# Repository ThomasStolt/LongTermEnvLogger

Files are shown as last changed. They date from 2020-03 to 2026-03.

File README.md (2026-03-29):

# Long Term Environment Logger

The aim of this project is to measure, store, display and evaluate the temperature in the rooms of a large building over an extended time period. This project has 2 main components:

A. The hardware of the sensor.

B. The server infrastructure to receive, store and display the measurements.

## The Hardware

1. An ultra-low power timer circuit that uses nano-Amps only when asleep and wakes up the entire circuit every approx. 5 minutes for measurement.

2. An LDO voltage regulator that regulates the incoming battery voltage from a LiIon battery to 3.3V

3. A battery voltage sensor that sends the battery voltage to the ESP8266 ADC pin with a voltage divider so that the battery voltage can be monitored.

4. The ESP8266 with a DS18B20 temperature sensor.

5. A small solar cell with a charging circuit, to keep the battery charged for as long as possible.

... and some additional mechanical and electronic components.

The ESP8266 was chosen as the microcontroller. It is versatile, very affordable, has more than enough functionality and information is easy to find.

If you think about it in detail, this project is not quite as trivial as it first appears. Some of the things to consider are:

* Runtime - How long does a single battery last?

  * As the battery-operated temperature sensors are to be distributed throughout a very large building, you want the individual sensors to run for as long as possible, so that you don't have to run around the building changing or charging batteries all the time. One option is the energy-saving mode ("DeepSleep") of the microcontroller. This would reduce the current draw during deep sleep to about 14µA. However, we want to achieve sleep current of less than 100nA! So, the normal Deep-Sleep will not do it.

* Update OTA(?)
	* It might be worth considering adding this capability. This would probably affect the runtime as well, because if we check for updates every time the circuit wakes up, it will cost runtime and energy. So, the question here is, how much runtime this would cost and is this really necessary?

* WiFi Connection Time
	* When the ESP8266 wakes up and has WiFi switched on, it draws about 70mA, which is a lot. So, all efforts need to be taken to reduce the connection time to be a short as possible.

* Power supply / battery
	* Li-Ion batteries are a good energy source for this type of project, especially the 18650 type. They are relatively inexpensive for their capacity. However, as these batteries are very sensitive to mishandling, it is important to take appropriate precautions.
		* How can you ensure that the LiIon battery will not be deep discharged?
		* How can I ensure that the LiIon battery cannot be overcharged?
		* How can I monitor the voltage of the power supply (of the LiIo battery) in order to replace or charge the battery in good time?
		* All batteries must be checked regularly for their capacity and possible health issues.

## Overview

First a short diagram for an overview:

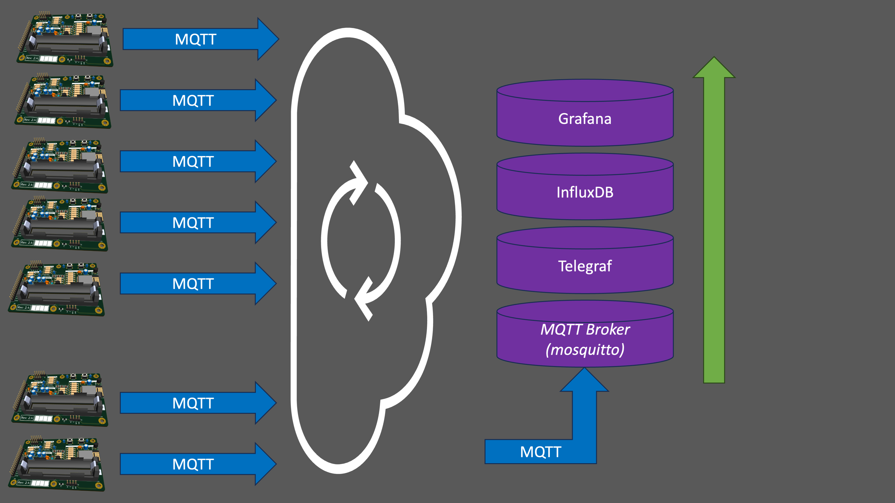
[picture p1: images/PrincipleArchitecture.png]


---

## Programmer Tool

An interactive TUI (terminal user interface) that programs each sensor in two steps. Built with [Textual](https://textual.textualize.io/) for a comfortable dark-mode interface.

### Features

- Auto-detects USB serial ports (OTA/network ports filtered out) and pre-selects the right one
- Live hotplug detection — plug in the adapter and it appears immediately
- Parallel background compilation while you prepare the hardware
- Auto-selects the WiFi network from your credentials file (strongest signal)
- Two-column credentials panel — file list on the left, network config on the right; press `E` to edit
- Per-location sensor registry (`sensors_home.csv`, `sensors_school.csv`, …) — switches automatically with the selected credentials file
- Always-visible Serial Debug panel showing raw ESP output during setup-sketch read
- Adjustable baud rate selector and automatic retry loop on serial read timeout
- Full keyboard navigation — no mouse required
- Clean two-step workflow with progress feedback

### Prerequisites

- [arduino-cli](https://arduino.github.io/arduino-cli/) with the ESP8266 core installed:
  ```bash
  arduino-cli core install esp8266:esp8266
  ```
- Python 3.10+
  ```bash
  pip install -r tool/requirements.txt
  ```

### Credentials Setup

```bash
cp credentials.example.h credentials_Home.h
# Edit credentials_Home.h and fill in your SSID and password
```

You can have multiple credential files for different locations:
- `credentials_Home.h`
- `credentials_School.h`

These files are gitignored — never commit real credentials.

### Board Configuration

Edit `tool/arduino_config.py` if needed:
```python
BOARD_FQBN = "esp8266:esp8266:generic"  # change for your ESP8266 variant
```

Common FQBNs:
- `esp8266:esp8266:generic` — bare ESP-01/ESP-12 modules
- `esp8266:esp8266:nodemcuv2` — NodeMCU v2 / Lolin
- `esp8266:esp8266:d1_mini` — Wemos D1 Mini

### Running the Tool

Connect the ESP8266 via USB-TTL adapter, then:

```bash
cd tool && python3 ltl_programmer.py
```

**Keyboard shortcuts:**

| Key | Action |
|-----|---|
| `F` | Start flash workflow |
| `R` | Refresh port list |
| `E` | Edit network config for selected credentials |
| `Q` | Quit |
| `Enter` | Confirm / Continue |

**Workflow:**

1. Select your USB-TTL adapter port (pre-selected automatically)
2. Select the credentials location (Home, School, …)
3. Press `F` to start — the tool guides you through:
   - Enter flash mode (RST + FLASH button sequence)
   - Setup sketch uploads and reads MAC address, DS18B20 address, and nearby WiFi
   - WiFi network is auto-selected from your credentials file
   - Enter a room number (1–254)
   - Production firmware compiles and uploads with all values baked in
4. Sensor is recorded in `tool/sensors_<location>.csv` (one file per credentials location)

### Flash Mode (ESP-12 / bare modules)

Bare ESP8266 modules without an auto-reset circuit require manual flash mode entry:

1. Press and hold **RST**
2. Press and hold **FLASH**
3. Release **RST**
4. Release **FLASH**

The tool will prompt you at the right moment.

### Manual Flash Fallback

If arduino-cli is not available, you can flash manually using the Arduino IDE:

1. Flash `code/LTL_setup/LTL_setup.ino` and open Serial Monitor at 115200 baud
2. Note the MAC address and DS18B20 address
3. Edit `code/LTL_sensor/LTL_sensor.ino` — replace the placeholder values
4. Copy your `credentials_<location>.h` to `credentials.h` in the same folder
5. Flash `code/LTL_sensor/LTL_sensor.ino`

### Sensor Registry

`tool/sensors_<location>.csv` tracks all programmed sensors per location (gitignored). For example, `sensors_home.csv` and `sensors_school.csv` are created automatically when you first flash a sensor using that credentials file.

| Field | Description |
|---|---|
| timestamp | When the sensor was programmed |
| room_number | Room number (also last IP octet) |
| mac_address | ESP8266 MAC address |
| ds18b20_address | DS18B20 OneWire address |
| location | Credentials location used |
| ssid | WiFi network name |
| bssid | Pinned BSSID (empty if not pinned) |
| channel | Pinned channel (empty if not pinned) |

### Battery Life Optimization

The production firmware (`code/LTL_sensor/LTL_sensor.ino`) reduces ESP8266 awake time by ~1060–1480ms per 5-minute cycle compared to the original firmware:

| Optimization | Saving |
|---|---|
| 9-bit DS18B20 resolution (±0.5°C) + async overlap | ~750ms |
| Hardcoded DS18B20 address (no bus scan) | ~10–30ms |
| Post-publish delays removed | ~300ms |
| **Total without BSSID pinning** | **~1060–1080ms** |
| Optional BSSID/channel pinning | +~200–400ms |
| **Total with BSSID pinning** | **~1260–1480ms** |

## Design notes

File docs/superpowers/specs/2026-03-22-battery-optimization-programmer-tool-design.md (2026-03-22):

# Design Spec: Battery Optimization & Programmer Tool
**Date:** 2026-03-22
**Project:** LongTermEnvLogger

---

## Overview

This spec covers two related improvements to the LongTermEnvLogger project:

1. **Optimized production firmware** (`LTL_sensor.ino`) — reduces ESP8266 awake time per cycle by ~1050–1480ms through sensor resolution reduction, async measurement overlap, hardcoded sensor address, and optional BSSID/channel pinning.
2. **Interactive programmer tool** (`ltl_programmer.py`) — a Python CLI tool that guides a two-step flash workflow: first a setup sketch to read hardware addresses and scan WiFi, then the final production firmware with all values baked in.

---

## Context

The ESP8266 is woken by external hardware every 5 minutes, measures temperature and battery voltage, publishes both to an MQTT broker, then cuts its own power by setting GPIO15 HIGH. Minimizing awake time directly extends battery life.

The existing code (`LTL_2024_01_07_01.ino`) already uses static IP and WiFi sleep before measurement. The main remaining inefficiencies are:
- DS18B20 operating at 12-bit resolution (750ms conversion, blocking)
- OneWire bus enumeration on every boot (~10–30ms)
- 300ms of post-publish delays of unclear necessity
- No BSSID/channel pinning (channel scan on every WiFi connect, ~200–400ms)

---

## Directory Structure

```
LongTermEnvLogger/
├── code/
│   ├── LTL_sensor/
│   │   └── LTL_sensor.ino          # optimized production firmware
│   └── LTL_setup/
│       └── LTL_setup.ino           # one-time setup sketch for configuration
├── tool/
│   ├── ltl_programmer.py           # interactive programmer tool
│   ├── sensors.csv                 # auto-maintained sensor registry (path relative to script)
│   └── arduino_config.py           # board FQBN and baud rate constants
├── credentials_Home.h              # gitignored, real credentials
├── credentials_School.h            # gitignored, real credentials
├── credentials.example.h           # in repo, template for new setups
└── README.md                       # updated with full workflow documentation
```

---

## Firmware Optimizations (`LTL_sensor.ino`)

### DS18B20 Resolution

Call `sensors.begin()` in `setup()` as before, then immediately call `sensors.setResolution(sensorAddr, 9)` to set 9-bit resolution. This must happen in `setup()`, after `sensors.begin()`, before `loop()` runs. It reduces conversion time from ~750ms to ~94ms.

```cpp
void setup() {
  WiFi.forceSleepBegin();
  sensors.begin();
  sensors.setResolution(sensorAddr, 9);   // set once; persists in sensor EEPROM
  pinMode(DONE, OUTPUT);
}
```

### Async Temperature Conversion

In `loop()`, use `sensors.setWaitForConversion(false)` before `requestTemperatures()`. The conversion runs in the background while WiFi connects (~2s) and the MQTT broker connects. The full blocking conversion time (~750ms at 12-bit) is removed from the critical path.

**Order of operations:**
```
setup():
  1. WiFi.forceSleepBegin()
  2. sensors.begin()
  3. sensors.setResolution(sensorAddr, 9)
  4. pinMode(DONE, OUTPUT)

loop():
  1. ADC voltage read (abort if below volt_limit)
  2. sensors.setWaitForConversion(false)
  3. requestTemperatures()          (returns immediately, starts 94ms conversion)
  4. setup_wifi()                   (~2000ms — conversion completes during this)
  5. reconnect()                    (MQTT connect — additional time buffer)
  6. sensors.getTempC(sensorAddr)   (data already ready; uses address, not index)
  7. publish temp + volt
  8. digitalWrite(DONE, HIGH)
```

**Note:** `getTempC(sensorAddr)` must be used (not `getTempCByIndex(0)`). `getTempCByIndex` triggers a bus re-enumeration and defeats the hardcoded-address optimisation.

**Race condition guard:** If BSSID pinning is enabled and WiFi connects faster than 94ms, the conversion may not be complete when `getTempC()` is called. The `reconnect()` call after `setup_wifi()` adds additional time (its internal `delay(100)` polling loop), but this is not guaranteed to be sufficient if the broker also responds immediately. Therefore: when `USE_BSSID` is defined, place `delay(100)` immediately before `getTempC(sensorAddr)` — after both `setup_wifi()` and `reconnect()` have returned — to guarantee 94ms has elapsed since `requestTemperatures()`. Without BSSID pinning the ~2s WiFi connect time makes this guard unnecessary.

### Hardcoded DS18B20 Address

The sensor address (8 bytes) is stored as a constant. This skips OneWire bus enumeration on every boot (~10–30ms).

```cpp
DeviceAddress sensorAddr = { 0x28, 0xXX, 0xXX, 0xXX, 0xXX, 0xXX, 0xXX, 0xXX };
```

This value is substituted by the programmer tool. See Template Substitution section.

### Optional BSSID/Channel Pinning

A compile-time flag enables BSSID + channel hardcoding, skipping the WiFi channel scan (~200–400ms). Disabled by default.

```cpp
// #define USE_BSSID   // uncomment to enable BSSID/channel pinning
#ifdef USE_BSSID
  const uint8_t wifi_bssid[6] = { 0xXX, 0xXX, 0xXX, 0xXX, 0xXX, 0xXX };
  const int wifi_channel = X;
#endif
```

The `WiFi.begin()` call must also be conditional:

```cpp
#ifdef USE_BSSID
  WiFi.begin(ssid, password, wifi_channel, wifi_bssid);
#else
  WiFi.begin(ssid, password);
#endif
```

When `USE_BSSID` is active, add `delay(100)` immediately before `getTempC(sensorAddr)` in `loop()` (see race condition guard above).

Note: The existing firmware has an unconditional `wifi_bssid` array (unused). The new code replaces this with the `#ifdef USE_BSSID` guard.

### Post-Publish Delays

The `delay(100)` and `delay(200)` after MQTT publishes are commented out. Their original purpose is unknown. A comment marks them for easy re-enabling if publish reliability issues arise.

```cpp
client.publish(temp_topic, tempString);
// delay(100);  // original delay, purpose unknown — re-enable if publish reliability issues occur
client.publish(volt_topic, payload);
// delay(200);  // original delay, purpose unknown — re-enable if publish reliability issues occur
```

### Timing Summary

| Optimisation | Critical-path saving |
|---|---|
| 9-bit + async overlap (removes full 750ms blocking call) | ~750ms |
| Hardcoded DS18B20 address (no bus enumeration) | ~10–30ms |
| Post-publish delays removed | ~300ms |
| **Total (without BSSID pinning)** | **~1060–1080ms** |
| Optional: BSSID/channel pinning | +~200–400ms |
| **Total (with BSSID pinning)** | **~1260–1480ms** |

---

## Setup Sketch (`LTL_setup.ino`)

Flashed once before the production firmware. On boot it outputs structured data over Serial at **115200 baud**.

### Output Format

Each line is prefixed with a token. The tool parses by prefix.

**MAC address** (one line):
```
MAC:AA:BB:CC:DD:EE:FF
```

**DS18B20 address** (one line, 8 bytes as uppercase hex, comma-separated, C-array style):
```
DS18B20:0x28,0xFF,0xA1,0xB2,0xC3,0xD4,0xE5,0x06
```

**WiFi networks** (one line per network, pipe-delimited fields: SSID|BSSID|channel|RSSI):
```
WIFI:MyNetwork|AA:BB:CC:DD:EE:FF|6|-72
WIFI:OtherNet|11:22:33:44:55:66|11|-85
```

**End marker** (signals all data has been sent):
```
SETUP_DONE
```

### Error Outputs

If no DS18B20 is found on the bus:
```
DS18B20:NOT_FOUND
```

If WiFi scan returns zero results:
```
WIFI:NONE
```

---

## Programmer Tool (`ltl_programmer.py`)

**Requirements:** Python 3.8+, `rich`, `pyserial`, `arduino-cli` in PATH.

### Board Configuration (`arduino_config.py`)

```python
BOARD_FQBN = "esp8266:esp8266:generic"   # adjust for your ESP8266 variant
BAUD_RATE = 115200
SERIAL_TIMEOUT_S = 30  # seconds to wait for SETUP_DONE before aborting
```

The FQBN can also be auto-detected via `arduino-cli board list` after connecting the device; the tool attempts auto-detection first and falls back to the configured constant.

### Tool Workflow

```
Step 1 — Hardware selection
  ├── Run `arduino-cli board list` to detect connected boards
  ├── Also enumerate serial ports via pyserial
  ├── Merge both lists into a single numbered list, deduplicated by port name
  │    (arduino-cli entry takes precedence when a port appears in both lists)
  └── User selects port (numbered list)

Step 2 — Location / credentials selection
  ├── Scan for credentials_*.h files in project root (relative to script location)
  └── User selects location (e.g. Home, School)

Step 3 — Flash setup sketch
  └── arduino-cli compile --fqbn <FQBN> + upload --port <PORT> LTL_setup.ino
      Error: if arduino-cli not found → print install instructions and abort

Step 4 — Read setup data (serial, timeout = SERIAL_TIMEOUT_S)
  ├── Read lines until SETUP_DONE or timeout
  ├── On timeout → print error, suggest checking baud rate and boot mode, abort
  ├── Parse MAC:     → store and display
  ├── Parse DS18B20: → if NOT_FOUND → print error "No DS18B20 detected", abort
  ├── Parse WIFI:    → collect all networks
  └── If WIFI:NONE   → print warning "No WiFi networks found", BSSID selection skipped

Step 5 — Configuration
  ├── Display WiFi networks as colored rich table (columns: #, SSID, BSSID, Ch, Signal bar)
  ├── Ask: "Select network number for BSSID pinning, or press Enter to skip"
  │    └── If skipped: BSSID/channel columns in CSV are written as empty string ""
  └── Enter room number (validated: integer 1–254, checked for uniqueness in sensors.csv)

Step 6 — Build and flash production firmware
  ├── Copy code/LTL_sensor/LTL_sensor.ino to a temp build directory
  ├── Apply template substitutions (see Template Substitution section)
  ├── Copy selected credentials_<location>.h to temp dir as credentials.h
  ├── arduino-cli compile + upload from temp dir
  └── On success: print confirmation panel

Step 7 — Update sensor registry
  └── Append row to tool/sensors.csv (path relative to script location)
```

### Template Substitution

`LTL_sensor.ino` contains placeholder tokens (C-style comments) that the tool replaces with `str.replace()`:

| Placeholder in .ino | Replaced with |
|---|---|
| `/*ROOM_NUMBER*/101` | actual room number |
| `/*DS18B20_ADDR*/{ 0x28, 0x00, 0x00, 0x00, 0x00, 0x00, 0x00, 0x00 }` | sensor address bytes |
| `// #define USE_BSSID` | `#define USE_BSSID` (if BSSID selected) |
| `/*BSSID*/{ 0x00,0x00,0x00,0x00,0x00,0x00 }` | selected BSSID bytes |
| `/*WIFI_CHANNEL*/1` | selected channel number |

The placeholder includes a default value so the template `.ino` compiles standalone in Arduino IDE without substitution.

**When BSSID pinning is skipped:** only the `USE_BSSID` line substitution is omitted (the line stays commented out). The `/*BSSID*/` and `/*WIFI_CHANNEL*/` placeholders are inside the disabled `#ifdef USE_BSSID` block and are compiled out — the tool does not need to substitute them in this case.

### CSV Schema

File: `tool/sensors.csv` (relative to script location).

```
timestamp,room_number,mac_address,ds18b20_address,location,ssid,bssid,channel
2026-03-22T14:30:00,101,AA:BB:CC:DD:EE:FF,0x28:0xFF:...,Home,MyNetwork,EE:55:A8:2C:A8:64,6
```

One row per programming event. Multiple rows for the same room number are allowed (history preserved). The tool warns if a room number already exists in the CSV and asks for confirmation before proceeding.

---

## Credentials Management

### File Format

`credentials_<location>.h`:
```cpp
const char* ssid = "MyNetwork";
const char* password = "MyPassword";
```

### Build-time inclusion

The tool copies the selected `credentials_<location>.h` to the temp build directory as `credentials.h`. The sketch `#include "credentials.h"` therefore always resolves. The original location-named file is never modified.

### Repository

- `credentials_*.h` files are listed in `.gitignore`
- `credentials.example.h` is committed as a template with placeholder values
- `README.md` documents: copy example → rename to `credentials_<location>.h` → fill in real values

---

## README Updates

The README will document:
1. **Prerequisites:** `arduino-cli` (with ESP8266 core installed), Python 3.8+, `pip install rich pyserial`
2. **Credentials setup:** copy `credentials.example.h`, rename to `credentials_<location>.h`, fill in values
3. **Full programmer tool workflow:** step-by-step with expected terminal output
4. **`arduino_config.py`:** how to set the correct FQBN for your ESP8266 variant
5. **Manual flash fallback:** for environments without arduino-cli

---

## Out of Scope

- No OTA update support
- No change to MQTT topic structure
- No change to 5-minute wake interval (controlled by external hardware)
- `volt_limit` constant remains hardcoded in the sketch (not configurable via tool)
- No Windows-specific serial port handling beyond what pyserial provides natively

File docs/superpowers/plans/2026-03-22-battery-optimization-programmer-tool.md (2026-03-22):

# Battery Optimization & Programmer Tool — Implementation Plan

> **For agentic workers:** REQUIRED SUB-SKILL: Use superpowers:subagent-driven-development (recommended) or superpowers:executing-plans to implement this plan task-by-task. Steps use checkbox (`- [ ]`) syntax for tracking.

**Goal:** Reduce ESP8266 awake time by ~1050–1480ms per 5-minute cycle and provide an interactive Python tool that flashes setup + production firmware with all sensor-specific values baked in.

**Architecture:** Two Arduino sketches (setup sketch outputs hardware info over serial; production sketch has hardcoded DS18B20 address, room number, optional BSSID). Python tool orchestrates two-step flash via arduino-cli, reads serial data, substitutes template placeholders, and maintains a CSV sensor registry.

**Tech Stack:** Arduino/ESP8266, C++, Python 3.8+, `rich`, `pyserial`, `pytest`, `arduino-cli`

**Spec:** `docs/superpowers/specs/2026-03-22-battery-optimization-programmer-tool-design.md`

---

## File Map

| File | Action | Responsibility |
|---|---|---|
| `code/LTL_sensor/LTL_sensor.ino` | Create | Optimized production firmware template |
| `code/LTL_setup/LTL_setup.ino` | Create | One-time setup sketch (MAC, DS18B20 addr, WiFi scan) |
| `tool/ltl_programmer.py` | Create | Interactive two-step programmer tool |
| `tool/arduino_config.py` | Create | Board FQBN, baud rate, timeout constants |
| `tool/requirements.txt` | Create | Python dependencies |
| `tool/tests/__init__.py` | Create | Makes tests a package |
| `tool/tests/test_utils.py` | Create | Unit tests for all pure utility functions |
| `credentials.example.h` | Create | Credential template for the repository |
| `.gitignore` | Modify | Add `credentials_*.h` pattern |
| `README.md` | Modify | Add programmer tool workflow section |

---

## Task 1: Project Scaffolding

**Files:**
- Modify: `.gitignore`
- Create: `credentials.example.h`
- Create: `tool/requirements.txt`
- Create: `tool/pytest.ini`
- Create: `tool/tests/__init__.py`

- [ ] **Step 1: Update .gitignore**

Replace current content of `.gitignore`:
```
credentials.h
credentials_*.h
.DS_Store
tool/sensors.csv
```

- [ ] **Step 2: Create credentials.example.h**

Create `credentials.example.h` in project root:
```cpp
// Copy this file to credentials_<location>.h (e.g. credentials_Home.h)
// and fill in your WiFi credentials.
// credentials_*.h files are gitignored — never commit real credentials.
const char* ssid = "YOUR_SSID_HERE";
const char* password = "YOUR_PASSWORD_HERE";
```

- [ ] **Step 3: Create tool/requirements.txt**

```
rich>=13.0.0
pyserial>=3.5
pytest>=7.0.0
```

- [ ] **Step 4: Create tool/pytest.ini**

```ini
[pytest]
testpaths = tests
```

- [ ] **Step 5: Create tool/tests/__init__.py**

Empty file:
```python
```

- [ ] **Step 6: Install dependencies**

```bash
cd tool && pip install -r requirements.txt
```

Expected: packages install without errors.

- [ ] **Step 7: Commit**

```bash
git add .gitignore credentials.example.h tool/requirements.txt tool/pytest.ini tool/tests/__init__.py
git commit -m "feat: add project scaffolding for programmer tool"
```

---

## Task 2: LTL_sensor.ino — Optimized Production Firmware

**Files:**
- Create: `code/LTL_sensor/LTL_sensor.ino`

This is the production firmware template. Placeholders (C-style comment tokens before default values) are substituted by `ltl_programmer.py` at flash time.

- [ ] **Step 1: Create code/LTL_sensor/LTL_sensor.ino**

```cpp
#include <ESP8266WiFi.h>
#include <PubSubClient.h>
#include <OneWire.h>
#include <DallasTemperature.h>
#include "credentials.h"

// Room number — substituted by ltl_programmer.py (must be 1–254, used as IP last octet)
const int roomNumber = /*ROOM_NUMBER*/101;

// DS18B20 sensor address — substituted by ltl_programmer.py
// Flash LTL_setup.ino once to discover this address
DeviceAddress sensorAddr = /*DS18B20_ADDR*/{ 0x28, 0x00, 0x00, 0x00, 0x00, 0x00, 0x00, 0x00 };

// Voltage limit (~2.7V) — prevents LiIon deep discharge
const int volt_limit = 560;

// Static IP (last octet = room number)
IPAddress staticIP(192, 168, 120, roomNumber);
IPAddress gateway(192, 168, 120, 1);
IPAddress subnet(255, 255, 255, 0);
IPAddress dns(192, 168, 120, 1);

// Optional BSSID/channel pinning — saves ~200-400ms per cycle by skipping WiFi channel scan.
// Only reliable with a single fixed access point on a manually configured fixed channel.
// ltl_programmer.py uncomments this line when a BSSID is selected during programming.
// #define USE_BSSID
#ifdef USE_BSSID
  const uint8_t wifi_bssid[6] = /*BSSID*/{ 0x00, 0x00, 0x00, 0x00, 0x00, 0x00 };
  const int wifi_channel = /*WIFI_CHANNEL*/1;
#endif

const char* mqtt_server = "192.168.120.2";
const int mqtt_port = 1883;
char temp_topic[30];
char volt_topic[30];

#define ONE_WIRE_BUS 12
#define DONE 15
OneWire oneWire(ONE_WIRE_BUS);
DallasTemperature sensors(&oneWire);

WiFiClient espClient;
PubSubClient client(espClient);

void setup_wifi() {
  unsigned long startAttemptTime = millis();
  WiFi.forceSleepWake();
  char hostname[11];
  sprintf(hostname, "sensor_%03d", roomNumber);
  WiFi.hostname(hostname);
  WiFi.config(staticIP, gateway, subnet, dns);
#ifdef USE_BSSID
  WiFi.begin(ssid, password, wifi_channel, wifi_bssid);
#else
  WiFi.begin(ssid, password);
#endif
  while (WiFi.status() != WL_CONNECTED && millis() - startAttemptTime < 5000) {
    delay(100);
  }
  if (WiFi.status() != WL_CONNECTED) {
    digitalWrite(DONE, HIGH);
    return;  // hardware cuts power immediately; return ensures no further code runs
  }
}

void reconnect() {
  char clientId[20];
  sprintf(clientId, "room_%03d", roomNumber);
  sprintf(temp_topic, "sensor/temp/%03d", roomNumber);
  sprintf(volt_topic, "sensor/volt/%03d", roomNumber);
  client.setServer(mqtt_server, mqtt_port);
  unsigned long startAttemptTime = millis();  // unsigned long matches millis() return type
  while (!client.connected()) {
    if (client.connect(clientId)) {
      break;
    } else {
      delay(100);
      if (millis() - startAttemptTime > 5000) {
        digitalWrite(DONE, HIGH);
        return;  // hardware cuts power immediately; return ensures no further code runs
      }
    }
  }
}

void setup() {
  WiFi.forceSleepBegin();
  sensors.begin();
  sensors.setResolution(sensorAddr, 9);  // 9-bit: ~94ms conversion, ±0.5°C. Persists in sensor EEPROM.
  pinMode(DONE, OUTPUT);
}

void loop() {
  // Check battery voltage — power off immediately if below deep-discharge limit
  int adcValue = analogRead(A0);
  if (adcValue < volt_limit) {
    digitalWrite(DONE, HIGH);
    return;
  }
  char voltPayload[5];
  snprintf(voltPayload, sizeof(voltPayload), "%d", adcValue);

  // Start async temperature conversion (94ms at 9-bit resolution).
  // WiFi + MQTT connect (~2s total) runs while the DS18B20 converts in the background,
  // so the conversion adds zero time to the critical path.
  sensors.setWaitForConversion(false);
  sensors.requestTemperatures();

  setup_wifi();
  if (!client.connected()) { reconnect(); }
  client.loop();

#ifdef USE_BSSID
  // With BSSID pinning, WiFi may connect in <94ms — add guard to ensure conversion is complete.
  delay(100);
#endif

  // Read temperature — conversion guaranteed complete by now
  float temperature = sensors.getTempC(sensorAddr);
  char tempString[8];
  dtostrf(temperature, 1, 2, tempString);

  client.publish(temp_topic, tempString);
  // delay(100);  // original delay — purpose unknown; re-enable if publish reliability issues occur
  client.publish(volt_topic, voltPayload);
  // delay(200);  // original delay — purpose unknown; re-enable if publish reliability issues occur

  // Cut power to the entire circuit
  digitalWrite(DONE, HIGH);
}
```

- [ ] **Step 2: Verify the template compiles in Arduino IDE (manual check)**

Open `code/LTL_sensor/LTL_sensor.ino` in Arduino IDE with a `credentials.h` present. It should compile without errors. The default DS18B20 placeholder address `{ 0x28, 0x00, ... }` is valid C++ and will compile fine (it just won't work until substituted).

- [ ] **Step 3: Commit**

```bash
git add code/LTL_sensor/LTL_sensor.ino
git commit -m "feat: add optimized LTL_sensor firmware template with async DS18B20 and placeholder tokens"
```

---

## Task 3: LTL_setup.ino — Setup Sketch

**Files:**
- Create: `code/LTL_setup/LTL_setup.ino`

This sketch runs once during programming. It outputs MAC address, DS18B20 address, and WiFi scan results over serial at 115200 baud. It does **not** need `credentials.h` (it scans WiFi without connecting).

- [ ] **Step 1: Create code/LTL_setup/LTL_setup.ino**

```cpp
#include <ESP8266WiFi.h>
#include <OneWire.h>
#include <DallasTemperature.h>

// LTL Setup Sketch
// Flash once to discover DS18B20 address, ESP MAC address, and nearby WiFi networks.
// Output is read by ltl_programmer.py to configure the production firmware.
// Serial: 115200 baud. Output ends with SETUP_DONE.

#define ONE_WIRE_BUS 12
OneWire oneWire(ONE_WIRE_BUS);
DallasTemperature sensors(&oneWire);

void setup() {
  Serial.begin(115200);
  delay(500);  // Let serial port stabilise after boot

  // MAC address
  WiFi.mode(WIFI_STA);
  Serial.print("MAC:");
  Serial.println(WiFi.macAddress());

  // DS18B20 address
  sensors.begin();
  if (sensors.getDeviceCount() == 0) {
    Serial.println("DS18B20:NOT_FOUND");
  } else {
    DeviceAddress addr;
    sensors.getAddress(addr, 0);
    Serial.print("DS18B20:");
    for (int i = 0; i < 8; i++) {
      if (i > 0) Serial.print(",");
      Serial.print("0x");
      if (addr[i] < 0x10) Serial.print("0");  // zero-pad single hex digits
      Serial.print(addr[i], HEX);
    }
    Serial.println();
  }

  // WiFi scan (no connection needed — passive scan only)
  int n = WiFi.scanNetworks();
  if (n == 0) {
    Serial.println("WIFI:NONE");
  } else {
    for (int i = 0; i < n; i++) {
      // Format: WIFI:SSID|BSSID|channel|RSSI
      Serial.print("WIFI:");
      Serial.print(WiFi.SSID(i));
      Serial.print("|");
      Serial.print(WiFi.BSSIDstr(i));
      Serial.print("|");
      Serial.print(WiFi.channel(i));
      Serial.print("|");
      Serial.println(WiFi.RSSI(i));
    }
  }

  Serial.println("SETUP_DONE");
}

void loop() {}  // nothing to do after setup
```

- [ ] **Step 2: Verify the sketch compiles in Arduino IDE (manual check)**

No `credentials.h` needed. Should compile cleanly.

- [ ] **Step 3: Commit**

```bash
git add code/LTL_setup/LTL_setup.ino
git commit -m "feat: add LTL_setup sketch for hardware discovery"
```

---

## Task 4: Tool Foundation — arduino_config.py and ltl_programmer.py Skeleton

**Files:**
- Create: `tool/arduino_config.py`
- Create: `tool/ltl_programmer.py`

- [ ] **Step 1: Create tool/arduino_config.py**

```python
# arduino_config.py — board configuration for ltl_programmer.py
# Adjust BOARD_FQBN to match your ESP8266 variant.
# Common values:
#   esp8266:esp8266:generic          — bare ESP-01/ESP-12 modules
#   esp8266:esp8266:nodemcuv2        — NodeMCU v2 / Lolin
#   esp8266:esp8266:d1_mini          — Wemos D1 Mini
BOARD_FQBN = "esp8266:esp8266:generic"
BAUD_RATE = 115200
SERIAL_TIMEOUT_S = 30  # seconds to wait for SETUP_DONE before aborting
BOOT_DELAY_S = 2       # seconds to wait for ESP8266 to boot after upload
```

- [ ] **Step 2: Create tool/ltl_programmer.py skeleton**

```python
#!/usr/bin/env python3
"""LTL Sensor Programmer — interactive two-step ESP8266 flash tool.

Workflow:
  1. Select serial port
  2. Select WiFi credentials location
  3. Flash LTL_setup sketch → read MAC, DS18B20 address, WiFi networks
  4. Configure room number and optional BSSID pinning
  5. Flash production firmware with values baked in
  6. Record to sensors.csv
"""

import csv
import os
import re
import shutil
import subprocess
import sys
import tempfile
import time
from datetime import datetime
from pathlib import Path

import serial
import serial.tools.list_ports
from rich.console import Console
from rich.panel import Panel
from rich.prompt import Confirm, IntPrompt, Prompt
from rich.table import Table

sys.path.insert(0, str(Path(__file__).parent))
from arduino_config import BAUD_RATE, BOARD_FQBN, BOOT_DELAY_S, SERIAL_TIMEOUT_S

console = Console()

# ── Paths ────────────────────────────────────────────────────────────────────
PROJECT_ROOT = Path(__file__).parent.parent
SETUP_SKETCH_DIR = PROJECT_ROOT / "code" / "LTL_setup"
SENSOR_SKETCH = PROJECT_ROOT / "code" / "LTL_sensor" / "LTL_sensor.ino"
CSV_PATH = Path(__file__).parent / "sensors.csv"
CSV_FIELDNAMES = [
    "timestamp", "room_number", "mac_address", "ds18b20_address",
    "location", "ssid", "bssid", "channel",
]

# ── Pure utility functions (unit-tested in tests/test_utils.py) ──────────────

# ── arduino-cli functions ────────────────────────────────────────────────────

# ── UI functions ─────────────────────────────────────────────────────────────

# ── Main workflow ─────────────────────────────────────────────────────────────

def main():
    console.print(Panel.fit(
        "[bold cyan]LTL Sensor Programmer[/bold cyan]\n"
        "Two-step ESP8266 flash tool",
        border_style="cyan",
    ))
    console.print("[yellow]Not yet implemented — run after completing all tasks.[/yellow]")

if __name__ == "__main__":
    main()
```

- [ ] **Step 3: Verify the skeleton runs**

```bash
cd tool && python ltl_programmer.py
```

Expected: prints the cyan header panel and the "Not yet implemented" message.

- [ ] **Step 4: Commit**

```bash
git add tool/arduino_config.py tool/ltl_programmer.py
git commit -m "feat: add tool foundation — arduino_config.py and ltl_programmer.py skeleton"
```

---

## Task 5: Serial Output Parser (TDD)

**Files:**
- Modify: `tool/ltl_programmer.py` (add `parse_serial_output`)
- Modify: `tool/tests/test_utils.py` (add parser tests)

- [ ] **Step 1: Write failing tests**

Create `tool/tests/test_utils.py`:

```python
import sys
from pathlib import Path
sys.path.insert(0, str(Path(__file__).parent.parent))

from ltl_programmer import parse_serial_output

def test_parse_full_output():
    lines = [
        "MAC:AA:BB:CC:DD:EE:FF",
        "DS18B20:0x28,0xFF,0xA1,0xB2,0xC3,0xD4,0xE5,0x06",
        "WIFI:HomeNet|AA:BB:CC:DD:EE:FF|6|-72",
        "WIFI:OtherNet|11:22:33:44:55:66|11|-85",
        "SETUP_DONE",
    ]
    result = parse_serial_output(lines)
    assert result["mac"] == "AA:BB:CC:DD:EE:FF"
    assert result["ds18b20"] == "0x28,0xFF,0xA1,0xB2,0xC3,0xD4,0xE5,0x06"
    assert result["ds18b20_error"] is False
    assert len(result["wifi_networks"]) == 2
    assert result["wifi_networks"][0] == {
        "ssid": "HomeNet", "bssid": "AA:BB:CC:DD:EE:FF", "channel": 6, "rssi": -72
    }
    assert result["wifi_none"] is False
    assert result["done"] is True

def test_parse_ds18b20_not_found():
    lines = ["MAC:AA:BB:CC:DD:EE:FF", "DS18B20:NOT_FOUND", "WIFI:NONE", "SETUP_DONE"]
    result = parse_serial_output(lines)
    assert result["ds18b20_error"] is True
    assert result["ds18b20"] is None
    assert result["wifi_none"] is True
    assert result["wifi_networks"] == []

def test_parse_incomplete_output():
    """Partial output — SETUP_DONE not yet received."""
    lines = ["MAC:AA:BB:CC:DD:EE:FF"]
    result = parse_serial_output(lines)
    assert result["mac"] == "AA:BB:CC:DD:EE:FF"
    assert result["done"] is False

def test_parse_crlf_line_endings():
    """Serial ports often produce \\r\\n — strip() must handle it."""
    lines = ["MAC:AA:BB:CC:DD:EE:FF\r", "SETUP_DONE\r"]
    result = parse_serial_output(lines)
    assert result["mac"] == "AA:BB:CC:DD:EE:FF"
    assert result["done"] is True
```

- [ ] **Step 2: Run tests — expect failure**

```bash
cd tool && pytest tests/test_utils.py -v
```

Expected: `ImportError` or `AttributeError` — `parse_serial_output` not yet defined.

- [ ] **Step 3: Add parse_serial_output to ltl_programmer.py**

Add under the `# ── Pure utility functions` comment:

```python
def parse_serial_output(lines: list) -> dict:
    """Parse lines from LTL_setup sketch serial output.

    Returns dict with keys:
      mac (str|None), ds18b20 (str|None), ds18b20_error (bool),
      wifi_networks (list[dict]), wifi_none (bool), done (bool)
    Each wifi_networks entry: {ssid, bssid, channel (int), rssi (int)}
    """
    result = {
        "mac": None,
        "ds18b20": None,
        "ds18b20_error": False,
        "wifi_networks": [],
        "wifi_none": False,
        "done": False,
    }
    for line in lines:
        line = line.strip()
        if line.startswith("MAC:"):
            result["mac"] = line[4:]
        elif line == "DS18B20:NOT_FOUND":
            result["ds18b20_error"] = True
        elif line.startswith("DS18B20:"):
            result["ds18b20"] = line[8:]
        elif line == "WIFI:NONE":
            result["wifi_none"] = True
        elif line.startswith("WIFI:"):
            parts = line[5:].split("|", 3)  # maxsplit=3 handles SSIDs containing '|'
            if len(parts) == 4:
                result["wifi_networks"].append({
                    "ssid": parts[0],
                    "bssid": parts[1],
                    "channel": int(parts[2]),
                    "rssi": int(parts[3]),
                })
        elif line == "SETUP_DONE":
            result["done"] = True
    return result
```

- [ ] **Step 4: Run tests — expect pass**

```bash
cd tool && pytest tests/test_utils.py -v
```

Expected: all 4 tests PASS.

- [ ] **Step 5: Commit**

```bash
git add tool/ltl_programmer.py tool/tests/test_utils.py
git commit -m "feat: add serial output parser with tests"
```

---

## Task 6: Address Formatter Utilities (TDD)

**Files:**
- Modify: `tool/ltl_programmer.py` (add `format_ds18b20_c_array`, `format_bssid_c_array`)
- Modify: `tool/tests/test_utils.py`

- [ ] **Step 1: Add failing tests to test_utils.py**

Append to `tool/tests/test_utils.py`:

```python
from ltl_programmer import format_ds18b20_c_array, format_bssid_c_array

def test_format_ds18b20_c_array():
    raw = "0x28,0xFF,0xA1,0xB2,0xC3,0xD4,0xE5,0x06"
    assert format_ds18b20_c_array(raw) == "{ 0x28, 0xFF, 0xA1, 0xB2, 0xC3, 0xD4, 0xE5, 0x06 }"

def test_format_ds18b20_c_array_wrong_length():
    import pytest
    with pytest.raises(ValueError, match="8 bytes"):
        format_ds18b20_c_array("0x28,0xFF,0xA1,0xB2,0xC3,0xD4,0xE5")  # only 7 bytes

def test_format_bssid_c_array():
    assert format_bssid_c_array("AA:BB:CC:DD:EE:FF") == "{ 0xAA, 0xBB, 0xCC, 0xDD, 0xEE, 0xFF }"

def test_format_bssid_c_array_lowercase():
    """pyserial/ESP may return lowercase hex — must uppercase."""
    assert format_bssid_c_array("aa:bb:cc:dd:ee:ff") == "{ 0xAA, 0xBB, 0xCC, 0xDD, 0xEE, 0xFF }"
```

- [ ] **Step 2: Run tests — expect failure**

```bash
cd tool && pytest tests/test_utils.py -v
```

Expected: 3 new tests fail with `ImportError`.

- [ ] **Step 3: Add formatter functions to ltl_programmer.py**

Add after `parse_serial_output`:

```python
def format_ds18b20_c_array(raw: str) -> str:
    """Convert DS18B20 serial format to C array literal.

    '0x28,0xFF,0xA1,0xB2,0xC3,0xD4,0xE5,0x06' → '{ 0x28, 0xFF, ... }'
    Raises ValueError if the address does not contain exactly 8 bytes.
    """
    parts = [p.strip() for p in raw.split(",")]
    if len(parts) != 8:
        raise ValueError(f"DS18B20 address must be 8 bytes, got {len(parts)}: {raw!r}")
    return "{ " + ", ".join(parts) + " }"

def format_bssid_c_array(bssid: str) -> str:
    """Convert BSSID string to C array literal.

    'AA:BB:CC:DD:EE:FF' → '{ 0xAA, 0xBB, 0xCC, 0xDD, 0xEE, 0xFF }'
    """
    parts = [f"0x{b.upper()}" for b in bssid.split(":")]
    return "{ " + ", ".join(parts) + " }"
```

- [ ] **Step 4: Run tests — expect all pass**

```bash
cd tool && pytest tests/test_utils.py -v
```

Expected: all tests up to this point PASS.

- [ ] **Step 5: Commit**

```bash
git add tool/ltl_programmer.py tool/tests/test_utils.py
git commit -m "feat: add DS18B20 and BSSID address formatter utilities with tests"
```

---

## Task 7: Template Substitution (TDD)

**Files:**
- Modify: `tool/ltl_programmer.py` (add `substitute_template`)
- Modify: `tool/tests/test_utils.py`

- [ ] **Step 1: Add failing tests**

Append to `tool/tests/test_utils.py`:

```python
from ltl_programmer import substitute_template

TEMPLATE = """\
const int roomNumber = /*ROOM_NUMBER*/101;
DeviceAddress sensorAddr = /*DS18B20_ADDR*/{ 0x28, 0x00, 0x00, 0x00, 0x00, 0x00, 0x00, 0x00 };
// #define USE_BSSID
#ifdef USE_BSSID
  const uint8_t wifi_bssid[6] = /*BSSID*/{ 0x00, 0x00, 0x00, 0x00, 0x00, 0x00 };
  const int wifi_channel = /*WIFI_CHANNEL*/1;
#endif
"""

def test_substitute_room_and_ds18b20():
    result = substitute_template(
        TEMPLATE,
        room_number=202,
        ds18b20_array="{ 0x28, 0xFF, 0xA1, 0xB2, 0xC3, 0xD4, 0xE5, 0x06 }",
    )
    assert "/*ROOM_NUMBER*/202" in result
    assert "/*DS18B20_ADDR*/{ 0x28, 0xFF, 0xA1" in result
    assert "// #define USE_BSSID" in result  # BSSID not selected — stays commented

def test_substitute_with_bssid():
    result = substitute_template(
        TEMPLATE,
        room_number=101,
        ds18b20_array="{ 0x28, 0xFF, 0xA1, 0xB2, 0xC3, 0xD4, 0xE5, 0x06 }",
        bssid_array="{ 0xAA, 0xBB, 0xCC, 0xDD, 0xEE, 0xFF }",
        channel=6,
    )
    assert "#define USE_BSSID" in result
    assert "// #define USE_BSSID" not in result  # comment removed
    assert "/*BSSID*/{ 0xAA, 0xBB" in result
    assert "/*WIFI_CHANNEL*/6" in result

def test_substitute_room_number_range():
    """Room 1 and 254 are boundary values."""
    for room in (1, 254):
        result = substitute_template(TEMPLATE, room_number=room, ds18b20_array="{ 0x28, 0x00, 0x00, 0x00, 0x00, 0x00, 0x00, 0x00 }")
        assert f"/*ROOM_NUMBER*/{room}" in result

def test_substitute_bssid_only_no_substitution():
    """Passing bssid_array without channel (or vice versa) leaves USE_BSSID commented out."""
    result = substitute_template(
        TEMPLATE,
        room_number=101,
        ds18b20_array="{ 0x28, 0x00, 0x00, 0x00, 0x00, 0x00, 0x00, 0x00 }",
        bssid_array="{ 0xAA, 0xBB, 0xCC, 0xDD, 0xEE, 0xFF }",
        channel=None,  # channel missing — pinning should NOT be activated
    )
    assert "// #define USE_BSSID" in result  # must stay commented
```

- [ ] **Step 2: Run tests — expect failure**

```bash
cd tool && pytest tests/test_utils.py -v
```

- [ ] **Step 3: Add substitute_template to ltl_programmer.py**

```python
def substitute_template(
    content: str,
    room_number: int,
    ds18b20_array: str,
    bssid_array: str = None,
    channel: int = None,
) -> str:
    """Apply placeholder substitutions to LTL_sensor.ino content.

    Placeholders use /*TOKEN*/default_value format so the template compiles
    standalone. Substitution preserves the placeholder comment for readability.
    """
    content = re.sub(
        r"/\*ROOM_NUMBER\*/\d+",
        f"/*ROOM_NUMBER*/{room_number}",
        content,
    )
    content = re.sub(
        r"/\*DS18B20_ADDR\*/\{[^}]+\}",
        f"/*DS18B20_ADDR*/{ds18b20_array}",
        content,
    )
    if bssid_array is not None and channel is not None:
        content = content.replace("// #define USE_BSSID", "#define USE_BSSID")
        content = re.sub(
            r"/\*BSSID\*/\{[^}]+\}",
            f"/*BSSID*/{bssid_array}",
            content,
        )
        content = re.sub(
            r"/\*WIFI_CHANNEL\*/\d+",
            f"/*WIFI_CHANNEL*/{channel}",
            content,
        )
    return content
```

- [ ] **Step 4: Run tests — expect all pass**

```bash
cd tool && pytest tests/test_utils.py -v
```

Expected: all tests up to this point PASS.

- [ ] **Step 5: Commit**

```bash
git add tool/ltl_programmer.py tool/tests/test_utils.py
git commit -m "feat: add template substitution with tests"
```

---

## Task 8: CSV Handler and Credentials Finder (TDD)

**Files:**
- Modify: `tool/ltl_programmer.py` (add `find_credentials_files`, `load_csv_rooms`, `append_csv_row`)
- Modify: `tool/tests/test_utils.py`

- [ ] **Step 1: Add failing tests**

Append to `tool/tests/test_utils.py`:

```python
import csv
import tempfile
from pathlib import Path
from ltl_programmer import find_credentials_files, load_csv_rooms, append_csv_row, CSV_FIELDNAMES

def test_find_credentials_files(tmp_path):
    (tmp_path / "credentials_Home.h").write_text('const char* ssid = "x";')
    (tmp_path / "credentials_School.h").write_text('const char* ssid = "y";')
    (tmp_path / "credentials.example.h").write_text("example")
    locations = find_credentials_files(tmp_path)
    assert set(locations) == {"Home", "School"}
    assert "example" not in locations  # example file excluded

def test_find_credentials_files_empty(tmp_path):
    assert find_credentials_files(tmp_path) == []

def test_load_csv_rooms_nonexistent(tmp_path):
    assert load_csv_rooms(tmp_path / "sensors.csv") == set()

def test_load_csv_rooms_with_data(tmp_path):
    csv_path = tmp_path / "sensors.csv"
    with open(csv_path, "w", newline="") as f:
        w = csv.DictWriter(f, fieldnames=CSV_FIELDNAMES)
        w.writeheader()
        w.writerow({"room_number": "101", "mac_address": "AA:BB:CC:DD:EE:FF",
                    "ds18b20_address": "", "location": "Home", "ssid": "",
                    "bssid": "", "channel": "", "timestamp": "2026-01-01T00:00:00"})
        w.writerow({"room_number": "202", "mac_address": "11:22:33:44:55:66",
                    "ds18b20_address": "", "location": "School", "ssid": "",
                    "bssid": "", "channel": "", "timestamp": "2026-01-02T00:00:00"})
    assert load_csv_rooms(csv_path) == {101, 202}

def test_append_csv_row_creates_file(tmp_path):
    csv_path = tmp_path / "sensors.csv"
    row = {"timestamp": "2026-03-22T14:30:00", "room_number": "101",
           "mac_address": "AA:BB:CC:DD:EE:FF", "ds18b20_address": "0x28,0xFF",
           "location": "Home", "ssid": "HomeNet", "bssid": "AA:BB:CC:DD:EE:FF", "channel": "6"}
    append_csv_row(csv_path, row)
    assert csv_path.exists()
    with open(csv_path) as f:
        lines = f.readlines()
    assert lines[0].startswith("timestamp")  # header present
    assert "101" in lines[1]

def test_append_csv_row_no_duplicate_header(tmp_path):
    csv_path = tmp_path / "sensors.csv"
    row = {"timestamp": "t", "room_number": "1", "mac_address": "", "ds18b20_address": "",
           "location": "", "ssid": "", "bssid": "", "channel": ""}
    append_csv_row(csv_path, row)
    append_csv_row(csv_path, row)
    with open(csv_path) as f:
        lines = [l for l in f.readlines() if l.strip()]
    # 1 header + 2 data rows = 3 lines
    assert len(lines) == 3
    assert lines[0].startswith("timestamp")
    assert lines[1].startswith("t")
```

- [ ] **Step 2: Run tests — expect failure**

```bash
cd tool && pytest tests/test_utils.py -v
```

- [ ] **Step 3: Add CSV and credentials functions to ltl_programmer.py**

```python
def find_credentials_files(project_root: Path) -> list:
    """Return sorted list of location names from credentials_<location>.h files.

    Excludes credentials.example.h.
    Example: ['Home', 'School'] for credentials_Home.h, credentials_School.h
    """
    return sorted(
        f.stem.replace("credentials_", "")
        for f in project_root.glob("credentials_*.h")
        if f.stem != "credentials_example"
    )

def load_csv_rooms(csv_path: Path) -> set:
    """Return set of room numbers (int) already recorded in sensors.csv."""
    if not csv_path.exists():
        return set()
    with open(csv_path, newline="") as f:
        reader = csv.DictReader(f)
        return {int(row["room_number"]) for row in reader if row.get("room_number")}

def append_csv_row(csv_path: Path, row: dict) -> None:
    """Append a row to sensors.csv, creating with header if the file is new."""
    write_header = not csv_path.exists()
    with open(csv_path, "a", newline="") as f:
        writer = csv.DictWriter(f, fieldnames=CSV_FIELDNAMES)
        if write_header:
            writer.writeheader()
        writer.writerow(row)
```

- [ ] **Step 4: Run all tests — expect all pass**

```bash
cd tool && pytest tests/test_utils.py -v
```

Expected: all 18 tests PASS.

- [ ] **Step 5: Commit**

```bash
git add tool/ltl_programmer.py tool/tests/test_utils.py
git commit -m "feat: add CSV handler and credentials finder with tests"
```

---

## Task 9: UI — Port Detection and Credentials Selection

**Files:**
- Modify: `tool/ltl_programmer.py` (add `detect_ports`, `select_port`, `select_credentials`)

These functions interact with the user — no automated tests. Verify manually.

- [ ] **Step 1: Add port detection and UI functions to ltl_programmer.py**

Add under `# ── UI functions`:

```python
def _rssi_bar(rssi: int) -> str:
    """Render a 5-block signal strength bar with color."""
    strength = min(max(rssi + 100, 0), 60) / 60
    bars = max(1, int(strength * 5))
    color = ["red", "red", "yellow", "green", "green"][min(bars - 1, 4)]
    return f"[{color}]{'█' * bars}{'░' * (5 - bars)}[/{color}] {rssi} dBm"

def detect_ports() -> list:
    """Return merged list of dicts with keys: port, description, fqbn.

    Runs `arduino-cli board list` first (gives FQBN for known boards).
    Falls back to pyserial for unrecognised ports.
    arduino-cli entries take precedence when a port appears in both.
    """
    ports_map = {}

    # pyserial baseline
    for p in serial.tools.list_ports.comports():
        ports_map[p.device] = {"port": p.device, "description": p.description, "fqbn": None}

    # arduino-cli overlay (may provide FQBN)
    try:
        result = subprocess.run(
            ["arduino-cli", "board", "list"],
            capture_output=True, text=True, timeout=10,
        )
        for line in result.stdout.splitlines()[1:]:  # skip header
            parts = line.split()
            if not parts:
                continue
            port = parts[0]
            fqbn = next((p for p in parts if ":" in p and p.count(":") == 2), None)
            if port in ports_map:
                ports_map[port]["fqbn"] = fqbn
            else:
                ports_map[port] = {"port": port, "description": " ".join(parts[1:3]), "fqbn": fqbn}
    except (FileNotFoundError, subprocess.TimeoutExpired):
        pass  # arduino-cli not available — pyserial list is sufficient

    return sorted(ports_map.values(), key=lambda x: x["port"])

def select_port() -> dict:
    """Display available serial ports and prompt user to select one.

    Returns dict with keys: port (str), fqbn (str|None).
    Aborts if no ports found.
    """
    ports = detect_ports()
    if not ports:
        console.print("[red]No serial ports found. Connect the ESP8266 via USB-TTL and retry.[/red]")
        sys.exit(1)

    table = Table(title="Available Serial Ports", border_style="blue")
    table.add_column("#", style="bold cyan", width=4)
    table.add_column("Port", style="white")
    table.add_column("Description", style="dim")
    table.add_column("Board (FQBN)", style="green")

    for i, p in enumerate(ports, 1):
        fqbn_display = p["fqbn"] or "[dim]unknown[/dim]"
        table.add_row(str(i), p["port"], p["description"], fqbn_display)

    console.print(table)
    while True:
        choice = IntPrompt.ask("Select port number", default=1)
        if 1 <= choice <= len(ports):
            break
        console.print(f"[red]Enter a number between 1 and {len(ports)}.[/red]")
    selected = ports[choice - 1]
    console.print(f"[green]Selected:[/green] {selected['port']}")
    return selected

def select_credentials() -> tuple:
    """Display available credentials_<location>.h files and prompt user to select.

    Returns (location_name: str, file_path: Path).
    Aborts if no credentials files found.
    """
    locations = find_credentials_files(PROJECT_ROOT)
    if not locations:
        console.print(
            "[red]No credentials files found.[/red]\n"
            f"Copy [cyan]credentials.example.h[/cyan] to "
            f"[cyan]credentials_<location>.h[/cyan] in [cyan]{PROJECT_ROOT}[/cyan] "
            "and fill in your WiFi credentials."
        )
        sys.exit(1)

    table = Table(title="Available Credentials", border_style="blue")
    table.add_column("#", style="bold cyan", width=4)
    table.add_column("Location", style="white")
    table.add_column("File", style="dim")

    for i, loc in enumerate(locations, 1):
        table.add_row(str(i), loc, f"credentials_{loc}.h")

    console.print(table)
    while True:
        choice = IntPrompt.ask("Select location number", default=1)
        if 1 <= choice <= len(locations):
            break
        console.print(f"[red]Enter a number between 1 and {len(locations)}.[/red]")
    location = locations[choice - 1]
    file_path = PROJECT_ROOT / f"credentials_{location}.h"
    console.print(f"[green]Selected:[/green] {location}")
    return location, file_path
```

- [ ] **Step 2: Manual verification**

Update `main()` temporarily to call these functions:
```python
def main():
    console.print(Panel.fit("[bold cyan]LTL Sensor Programmer[/bold cyan]", border_style="cyan"))
    port_info = select_port()
    location, cred_path = select_credentials()
    console.print(f"Port: {port_info['port']}, Credentials: {cred_path}")
```

Run `python ltl_programmer.py` with an ESP8266 connected. Verify:
- Port table shows connected device
- Credentials table shows your `credentials_*.h` files
- Selection works correctly

Revert the temporary main() change after verification (it will be replaced in Task 12).

- [ ] **Step 3: Commit**

```bash
git add tool/ltl_programmer.py
git commit -m "feat: add port detection and credentials selection UI"
```

---

## Task 10: UI — Flash Setup Sketch and Read Serial Data

**Files:**
- Modify: `tool/ltl_programmer.py` (add `flash_sketch`, `read_setup_data`)

- [ ] **Step 1: Add arduino-cli flash function**

Add under `# ── arduino-cli functions`:

```python
def _resolve_fqbn(port_fqbn: str) -> str:
    """Return port FQBN if known, otherwise fall back to arduino_config.BOARD_FQBN."""
    return port_fqbn if port_fqbn else BOARD_FQBN

def flash_sketch(sketch_dir: Path, port: str, fqbn: str) -> None:
    """Compile and upload a sketch directory via arduino-cli.

    Aborts with a message if arduino-cli is not in PATH or compilation fails.
    """
    if not shutil.which("arduino-cli"):
        console.print(
            "[red]arduino-cli not found in PATH.[/red]\n"
            "Install it from: https://arduino.github.io/arduino-cli/\n"
            "Then install the ESP8266 core: "
            "[cyan]arduino-cli core install esp8266:esp8266[/cyan]"
        )
        sys.exit(1)

    with console.status(f"[cyan]Compiling {sketch_dir.name}...[/cyan]"):
        result = subprocess.run(
            ["arduino-cli", "compile", "--fqbn", fqbn, str(sketch_dir)],
            capture_output=True, text=True,
        )
    if result.returncode != 0:
        console.print(f"[red]Compilation failed:[/red]\n{result.stderr}")
        sys.exit(1)
    console.print("[green]Compilation successful.[/green]")

    with console.status(f"[cyan]Uploading to {port}...[/cyan]"):
        result = subprocess.run(
            ["arduino-cli", "upload", "--fqbn", fqbn, "--port", port, str(sketch_dir)],
            capture_output=True, text=True,
        )
    if result.returncode != 0:
        console.print(f"[red]Upload failed:[/red]\n{result.stderr}")
        sys.exit(1)
    console.print("[green]Upload successful.[/green]")
```

- [ ] **Step 2: Add serial reader function**

```python
def read_setup_data(port: str) -> dict:
    """Open serial port, read lines until SETUP_DONE or timeout.

    Returns parsed result dict from parse_serial_output().
    Aborts on timeout with a helpful error message.
    """
    console.print(f"[cyan]Reading setup data from {port} (timeout: {SERIAL_TIMEOUT_S}s)...[/cyan]")
    lines = []
    try:
        with serial.Serial(port, BAUD_RATE, timeout=1) as ser:
            deadline = time.time() + SERIAL_TIMEOUT_S
            with console.status("[cyan]Waiting for SETUP_DONE...[/cyan]"):
                while time.time() < deadline:
                    line = ser.readline().decode("utf-8", errors="replace").strip()
                    if line:
                        lines.append(line)
                    result = parse_serial_output(lines)
                    if result["done"]:
                        return result
    except serial.SerialException as e:
        console.print(f"[red]Serial error: {e}[/red]")
        sys.exit(1)

    console.print(
        "[red]Timeout — no SETUP_DONE received within "
        f"{SERIAL_TIMEOUT_S}s.[/red]\n"
        "Troubleshooting:\n"
        "  • Verify baud rate is 115200 in arduino_config.py\n"
        "  • Ensure device booted in run mode (not flash mode)\n"
        "  • Check that the correct port was selected"
    )
    sys.exit(1)
```

- [ ] **Step 3: Manual verification with hardware**

Temporarily in `main()`:
```python
port_info = select_port()
location, cred_path = select_credentials()
fqbn = _resolve_fqbn(port_info["fqbn"])
flash_sketch(SETUP_SKETCH_DIR, port_info["port"], fqbn)
import time; time.sleep(2)  # wait for ESP8266 to boot
data = read_setup_data(port_info["port"])
console.print(data)
```

Run and verify:
- Sketch compiles and uploads
- MAC address printed correctly
- DS18B20 address printed (or NOT_FOUND if no sensor connected)
- WiFi networks listed

Revert temporary main() after verification.

- [ ] **Step 4: Commit**

```bash
git add tool/ltl_programmer.py
git commit -m "feat: add arduino-cli flash and serial data reader"
```

---

## Task 11: UI — WiFi Table Display and Configuration Input

**Files:**
- Modify: `tool/ltl_programmer.py` (add `display_setup_results`, `get_configuration`)

- [ ] **Step 1: Add display and input functions**

```python
def display_setup_results(data: dict) -> None:
    """Display MAC address and WiFi networks from setup data."""
    console.print(Panel(
        f"[bold]MAC Address:[/bold] [cyan]{data['mac']}[/cyan]",
        title="ESP8266 Hardware Info",
        border_style="green",
    ))

    if data["ds18b20_error"]:
        console.print("[red]DS18B20 not found on OneWire bus.[/red] "
                      "Check wiring (data wire to GPIO12, 4.7kΩ pull-up to 3.3V).")
        sys.exit(1)

    console.print(f"[bold]DS18B20 address:[/bold] [cyan]{data['ds18b20']}[/cyan]")

    if data["wifi_none"]:
        console.print("[yellow]No WiFi networks found — BSSID pinning not available.[/yellow]")
        return

    table = Table(title="Nearby WiFi Networks", border_style="blue")
    table.add_column("#", style="bold cyan", width=4)
    table.add_column("SSID", style="white", min_width=20)
    table.add_column("BSSID", style="dim")
    table.add_column("Ch", style="yellow", width=4)
    table.add_column("Signal", min_width=18)

    for i, net in enumerate(data["wifi_networks"], 1):
        table.add_row(
            str(i),
            net["ssid"],
            net["bssid"],
            str(net["channel"]),
            _rssi_bar(net["rssi"]),
        )
    console.print(table)

def get_configuration(data: dict, existing_rooms: set) -> dict:
    """Prompt user for room number and optional BSSID selection.

    Returns dict with keys:
      room_number (int), bssid (str|None), channel (int|None), ssid (str|None)
    """
    # BSSID selection
    bssid = None
    channel = None
    ssid = None

    if not data["wifi_none"] and data["wifi_networks"]:
        console.print("\n[bold]BSSID Pinning[/bold] (optional — saves ~200–400ms per cycle)")
        console.print("Only use this if the ESP will always connect to a single, fixed access point.")
        raw = Prompt.ask(
            "Select network # to pin BSSID, or press [bold]Enter[/bold] to skip",
            default="",
        )
        if raw.strip().isdigit():
            idx = int(raw.strip()) - 1
            if 0 <= idx < len(data["wifi_networks"]):
                net = data["wifi_networks"][idx]
                bssid = net["bssid"]
                channel = net["channel"]
                ssid = net["ssid"]
                console.print(f"[green]BSSID pinned:[/green] {bssid} (channel {channel})")
            else:
                console.print("[yellow]Invalid selection — skipping BSSID pinning.[/yellow]")
        else:
            console.print("[dim]BSSID pinning skipped.[/dim]")

    # Room number
    while True:
        room_number = IntPrompt.ask("\nEnter room number", default=101)
        if not (1 <= room_number <= 254):
            console.print("[red]Room number must be between 1 and 254.[/red]")
            continue
        if room_number in existing_rooms:
            console.print(
                f"[yellow]Room {room_number} already exists in sensors.csv.[/yellow]"
            )
            if not Confirm.ask("Continue anyway?", default=False):
                continue
        break

    return {"room_number": room_number, "bssid": bssid, "channel": channel, "ssid": ssid}
```

- [ ] **Step 2: Manual verification with hardware**

Temporarily call `display_setup_results(data)` and `get_configuration(data, set())` in main() with real data from Task 10 verification. Verify the WiFi table renders with colored signal bars, BSSID selection works, room number validation rejects 0 and 255.

- [ ] **Step 3: Commit**

```bash
git add tool/ltl_programmer.py
git commit -m "feat: add WiFi display and configuration input UI"
```

---

## Task 12: UI — Generate + Flash Production Firmware + Update CSV + main()

**Files:**
- Modify: `tool/ltl_programmer.py` (add `build_and_flash_production`, complete `main()`)

- [ ] **Step 1: Add production firmware builder**

```python
def build_and_flash_production(
    config: dict,
    setup_data: dict,
    cred_path: Path,
    port: str,
    fqbn: str,
) -> None:
    """Substitute template, copy credentials, compile and upload production firmware."""
    template_content = SENSOR_SKETCH.read_text()

    ds18b20_array = format_ds18b20_c_array(setup_data["ds18b20"])
    bssid_array = format_bssid_c_array(config["bssid"]) if config["bssid"] else None

    final_content = substitute_template(
        template_content,
        room_number=config["room_number"],
        ds18b20_array=ds18b20_array,
        bssid_array=bssid_array,
        channel=config["channel"],
    )

    with tempfile.TemporaryDirectory() as tmpdir:
        sketch_dir = Path(tmpdir) / "LTL_sensor"
        sketch_dir.mkdir()
        (sketch_dir / "LTL_sensor.ino").write_text(final_content)
        shutil.copy(cred_path, sketch_dir / "credentials.h")

        console.print(Panel(
            f"Room:     [cyan]{config['room_number']}[/cyan]\n"
            f"DS18B20:  [cyan]{ds18b20_array}[/cyan]\n"
            f"BSSID:    [cyan]{config['bssid'] or 'not pinned'}[/cyan]\n"
            f"Channel:  [cyan]{config['channel'] or '—'}[/cyan]\n"
            f"Location: [cyan]{cred_path.stem.replace('credentials_', '')}[/cyan]",
            title="Production Firmware Configuration",
            border_style="green",
        ))

        flash_sketch(sketch_dir, port, fqbn)

    console.print(Panel(
        f"[bold green]Sensor {config['room_number']} programmed successfully![/bold green]",
        border_style="green",
    ))
```

- [ ] **Step 2: Complete main()**

Replace the placeholder `main()` with:

```python
def main():
    console.print(Panel.fit(
        "[bold cyan]LTL Sensor Programmer[/bold cyan]\n"
        "Two-step ESP8266 flash tool",
        border_style="cyan",
    ))

    # Step 1 — Hardware selection
    port_info = select_port()
    fqbn = _resolve_fqbn(port_info["fqbn"])
    port = port_info["port"]

    # Step 2 — Credentials selection
    location, cred_path = select_credentials()

    # Step 3 — Flash setup sketch
    console.rule("[bold]Step 1/2 — Setup Sketch[/bold]")
    flash_sketch(SETUP_SKETCH_DIR, port, fqbn)

    # Step 4 — Read setup data
    time.sleep(BOOT_DELAY_S)  # wait for ESP8266 to boot after upload
    setup_data = read_setup_data(port)

    # Step 5 — Display results and configure
    console.rule("[bold]Configuration[/bold]")
    display_setup_results(setup_data)
    existing_rooms = load_csv_rooms(CSV_PATH)
    config = get_configuration(setup_data, existing_rooms)

    # Step 6 — Build and flash production firmware
    console.rule("[bold]Step 2/2 — Production Firmware[/bold]")
    build_and_flash_production(config, setup_data, cred_path, port, fqbn)

    # Step 7 — Update CSV
    ssid = config["ssid"] or ""
    row = {
        "timestamp": datetime.now().isoformat(timespec="seconds"),
        "room_number": str(config["room_number"]),
        "mac_address": setup_data["mac"] or "",
        "ds18b20_address": setup_data["ds18b20"] or "",
        "location": location,
        "ssid": ssid,
        "bssid": config["bssid"] or "",
        "channel": str(config["channel"]) if config["channel"] else "",
    }
    append_csv_row(CSV_PATH, row)
    console.print(f"[green]Sensor registry updated:[/green] {CSV_PATH}")

    console.print(Panel(
        f"[bold green]Done![/bold green]\n"
        f"Room [cyan]{config['room_number']}[/cyan] is ready to deploy.",
        border_style="green",
    ))
```

- [ ] **Step 3: Full end-to-end test with hardware**

Run the complete tool:
```bash
cd tool && python ltl_programmer.py
```

Verify the full workflow:
1. Port table appears and selection works
2. Credentials selection works
3. LTL_setup sketch compiles and uploads
4. MAC, DS18B20, WiFi networks displayed correctly
5. BSSID selection and room number input work
6. Production firmware compiles with correct values
7. Production firmware uploads
8. sensors.csv created/updated with correct row
9. Success panel shown

After the ESP resets, open MQTT broker and confirm temperature and voltage messages arrive on `sensor/temp/XXX` and `sensor/volt/XXX`.

- [ ] **Step 4: Run full test suite one final time**

```bash
cd tool && pytest tests/test_utils.py -v
```

Expected: all 18 tests PASS.

- [ ] **Step 5: Commit**

```bash
git add tool/ltl_programmer.py
git commit -m "feat: add production firmware builder and complete main() workflow"
```

---

## Task 13: README.md Update

**Files:**
- Modify: `README.md`

- [ ] **Step 1: Add programmer tool section to README.md**

Append the following section to `README.md` (after the existing Hardware section):

```markdown
## Programmer Tool

An interactive Python tool that programs each sensor in two steps:
1. Flashes a setup sketch that reads the DS18B20 address, MAC address, and nearby WiFi networks
2. Flashes the optimized production firmware with all values baked in

### Prerequisites

- [arduino-cli](https://arduino.github.io/arduino-cli/) with the ESP8266 core installed:
  ```bash
  arduino-cli core install esp8266:esp8266
  ```
- Python 3.8+
  ```bash
  pip install rich pyserial
  ```

### Credentials Setup

```bash
cp credentials.example.h credentials_Home.h
# Edit credentials_Home.h and fill in your SSID and password
```

You can have multiple credential files for different locations:
- `credentials_Home.h`
- `credentials_School.h`

These files are gitignored — never commit real credentials.

### Board Configuration

Edit `tool/arduino_config.py` if needed:
```python
BOARD_FQBN = "esp8266:esp8266:generic"  # change for your ESP8266 variant
```

Common FQBNs:
- `esp8266:esp8266:generic` — bare ESP-01/ESP-12 modules
- `esp8266:esp8266:nodemcuv2` — NodeMCU v2 / Lolin
- `esp8266:esp8266:d1_mini` — Wemos D1 Mini

### Running the Tool

Connect the ESP8266 via USB-TTL adapter, then:

```bash
cd tool && python ltl_programmer.py
```

The tool will:
1. Show available serial ports — select your USB-TTL adapter
2. Show available credential locations — select the right one
3. Flash the setup sketch and read hardware info
4. Show nearby WiFi networks — optionally pin a BSSID for faster connection
5. Ask for the room number (1–254)
6. Flash the production firmware with all values hardcoded
7. Record the sensor to `tool/sensors.csv`

### Manual Flash Fallback

If arduino-cli is not available, you can flash manually using the Arduino IDE:

1. Flash `code/LTL_setup/LTL_setup.ino` and open Serial Monitor at 115200 baud
2. Note the MAC address, DS18B20 address, and chosen WiFi network
3. Edit `code/LTL_sensor/LTL_sensor.ino` manually — replace the placeholder values
4. Copy your `credentials_<location>.h` to `credentials.h` in the same folder
5. Flash `code/LTL_sensor/LTL_sensor.ino`

### Sensor Registry

`tool/sensors.csv` tracks all programmed sensors:

| Field | Description |
|---|---|
| timestamp | When the sensor was programmed |
| room_number | Room number (also last IP octet) |
| mac_address | ESP8266 MAC address |
| ds18b20_address | DS18B20 OneWire address |
| location | Credentials location used |
| ssid | WiFi network name |
| bssid | Pinned BSSID (empty if not pinned) |
| channel | Pinned channel (empty if not pinned) |

### Battery Life Optimization

The production firmware reduces ESP8266 awake time by ~1060–1480ms per 5-minute cycle:

| Optimization | Saving |
|---|---|
| 9-bit DS18B20 resolution (±0.5°C) + async overlap | ~750ms |
| Hardcoded DS18B20 address (no bus scan) | ~10–30ms |
| Post-publish delays removed | ~300ms |
| **Total without BSSID pinning** | **~1060–1080ms** |
| Optional BSSID/channel pinning | +~200–400ms |
| **Total with BSSID pinning** | **~1260–1480ms** |
```

- [ ] **Step 2: Commit**

```bash
git add README.md
git commit -m "docs: add programmer tool documentation to README"
```

---

## Final Verification Checklist

- [ ] All 18 pytest tests pass: `cd tool && pytest -v`
- [ ] `LTL_sensor.ino` compiles in Arduino IDE with a `credentials.h` present
- [ ] `LTL_setup.ino` compiles without `credentials.h`
- [ ] Full programmer tool workflow runs end-to-end with real hardware
- [ ] `sensors.csv` is created/updated correctly
- [ ] MQTT broker receives messages on `sensor/temp/XXX` and `sensor/volt/XXX`
- [ ] `credentials_*.h` files are gitignored (run `git status` to verify)

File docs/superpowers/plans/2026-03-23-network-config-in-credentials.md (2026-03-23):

# Network Config in credentials.h — Implementation Plan

> **For agentic workers:** REQUIRED SUB-SKILL: Use superpowers:subagent-driven-development (recommended) or superpowers:executing-plans to implement this plan task-by-task. Steps use checkbox (`- [ ]`) syntax for tracking.

**Goal:** Move all hardcoded network parameters (IP prefix, subnet mask, MQTT broker) out of `LTL_sensor.ino` and into `credentials_<location>.h` so that selecting a credentials file is the only step required to target a different network.

**Architecture:** Four files are touched. `credentials.example.h` gains five new constants. `LTL_sensor.ino` replaces its hardcoded `192.168.120.x` values with those constants, using a compile-time CIDR-to-mask conversion guarded by a `static_assert`. `ltl_programmer.py` gains a pure helper function `read_network_from_credentials()` and a new `#creds-info` Static widget that shows the parsed network info for the selected credentials file. All existing real `credentials_*.h` files must be updated before flashing.

**Tech Stack:** Arduino/C++ (ESP8266), Python 3.10+, Textual TUI framework, pytest.

---

## File Map

| File | Action | What changes |
|---|---|---|
| `credentials.example.h` | Modify | Add `net_a/b/c`, `net_mask`, `mqtt_server`, `mqtt_port` |
| `code/LTL_sensor/LTL_sensor.ino` | Modify | Remove hardcoded IPs; add `static_assert` + `constexpr` subnet; use credentials constants |
| `tool/ltl_programmer.py` | Modify | Add `read_network_from_credentials()`; add `#creds-info` widget; handle `DataTable.RowHighlighted` |
| `tool/tests/test_utils.py` | Modify | Add import + 5 test cases for `read_network_from_credentials()` |

---

## Task 1: Update credentials.example.h

**Files:**
- Modify: `credentials.example.h`

- [ ] **Step 1: Open the file and confirm current contents**

  Read `credentials.example.h`. It should contain only `ssid` and `password`. Confirm before editing.

- [ ] **Step 2: Replace the file with the updated template**

  Replace the entire file content with:

  ```c
  // Copy this file to credentials_<location>.h (e.g. credentials_Home.h)
  // and fill in your WiFi credentials and network configuration.
  // credentials_*.h files are gitignored — never commit real credentials.
  const char*    ssid        = "YOUR_SSID_HERE";
  const char*    password    = "YOUR_PASSWORD_HERE";

  // Netzwerk-Präfix (erste 3 Oktette der statischen Sensor-IP)
  // Statische IP wird zu net_a.net_b.net_c.<Raumnummer>
  // Gateway und DNS werden als net_a.net_b.net_c.1 abgeleitet
  const uint8_t  net_a       = 192;
  const uint8_t  net_b       = 168;
  const uint8_t  net_c       = 120;

  // Subnetzmaske als CIDR-Präfixlänge (1–30)
  // 24 → 255.255.255.0  (Class C, typisch Heimnetz / Schulnetz)
  // 16 → 255.255.0.0    (Class B)
  //  8 → 255.0.0.0      (Class A)
  const uint8_t  net_mask    = 24;

  // MQTT-Broker (IP-Adresse als String; Hostname wird nicht unterstützt)
  const char*    mqtt_server = "192.168.120.2";
  const int      mqtt_port   = 1883;
  ```

- [ ] **Step 3: Commit**

  ```bash
  git add credentials.example.h
  git commit -m "feat: add network config fields to credentials.example.h"
  ```

---

## Task 2: Add read_network_from_credentials() with tests (TDD)

**Files:**
- Modify: `tool/tests/test_utils.py`
- Modify: `tool/ltl_programmer.py`

> **Pre-existing state to be aware of:** Before this task begins, `tool/tests/test_utils.py` currently imports `format_bssid_c_array` and `append_csv_row`, but **neither function exists in `ltl_programmer.py`**. This means the full test suite is already failing before any of our changes. Running `pytest` before Step 1 will show errors for those missing imports. This is a pre-existing gap; our import update in Step 1 restores both names. The expected failure in Step 3 below targets the new `read_network_from_credentials` import only — if you see failures on `format_bssid_c_array` or `append_csv_row` first, that confirms the pre-existing state and is expected to be resolved by Step 1.

### Step 2a — Write the failing tests first

- [ ] **Step 1: Add the import to test_utils.py**

  In `tool/tests/test_utils.py`, find the import block at the top (lines 8–17). Add `read_network_from_credentials` to the import list:

  ```python
  from ltl_programmer import (
      parse_serial_output,
      format_ds18b20_c_array,
      format_bssid_c_array,
      substitute_template,
      find_credentials_files,
      read_network_from_credentials,
      load_csv_rooms,
      append_csv_row,   # keep — used by existing test_append_csv_row_* tests
      CSV_FIELDNAMES,
  )
  ```

- [ ] **Step 2: Append the five new test cases to test_utils.py**

  Add at the end of `tool/tests/test_utils.py`:

  ```python
  # ── read_network_from_credentials tests ───────────────────────────────────────

  _VALID_CREDS = """\
  const char*    ssid        = "TestNet";
  const char*    password    = "secret";
  const uint8_t  net_a       = 10;
  const uint8_t  net_b       = 0;
  const uint8_t  net_c       = 5;
  const uint8_t  net_mask    = 24;
  const char*    mqtt_server = "10.0.5.2";
  const int      mqtt_port   = 1883;
  """

  def test_read_network_valid(tmp_path):
      cred = tmp_path / "credentials_Test.h"
      cred.write_text(_VALID_CREDS)
      result = read_network_from_credentials(cred)
      assert result == {
          "net_prefix": "10.0.5",
          "net_mask": 24,
          "mqtt_server": "10.0.5.2",
          "mqtt_port": 1883,
      }

  def test_read_network_missing_net_mask(tmp_path):
      cred = tmp_path / "credentials_Test.h"
      cred.write_text(_VALID_CREDS.replace("const uint8_t  net_mask    = 24;\n", ""))
      assert read_network_from_credentials(cred) is None

  def test_read_network_missing_mqtt_server(tmp_path):
      cred = tmp_path / "credentials_Test.h"
      cred.write_text(_VALID_CREDS.replace('const char*    mqtt_server = "10.0.5.2";\n', ""))
      assert read_network_from_credentials(cred) is None

  def test_read_network_unreadable_file(tmp_path):
      assert read_network_from_credentials(tmp_path / "nonexistent.h") is None

  def test_read_network_nonstandard_port(tmp_path):
      cred = tmp_path / "credentials_Test.h"
      cred.write_text(_VALID_CREDS.replace("mqtt_port   = 1883", "mqtt_port   = 8883"))
      result = read_network_from_credentials(cred)
      assert result is not None
      assert result["mqtt_port"] == 8883
  ```

- [ ] **Step 3: Run the tests — confirm they fail with ImportError**

  ```bash
  cd tool && pytest tests/test_utils.py::test_read_network_valid -v
  ```

  Expected: `ImportError: cannot import name 'read_network_from_credentials'`

### Step 2b — Implement the function

- [ ] **Step 4: Add read_network_from_credentials() to ltl_programmer.py**

  In `tool/ltl_programmer.py`, find the `read_ssid_from_credentials` function (around line 134). Add the new function immediately after it:

  ```python
  def read_network_from_credentials(cred_path: Path) -> dict | None:
      """Parse network config from a credentials_*.h file.

      Returns a dict with keys: net_prefix (str), net_mask (int),
      mqtt_server (str), mqtt_port (int).
      Returns None if any required field is missing or the file is unreadable.
      """
      try:
          content = cred_path.read_text()
      except OSError:
          return None
      octets = re.findall(r'const\s+uint8_t\s+net_([abc])\s*=\s*(\d+)', content)
      octet_map = {k: int(v) for k, v in octets}
      if not all(k in octet_map for k in ("a", "b", "c")):
          return None
      m_mask = re.search(r'const\s+uint8_t\s+net_mask\s*=\s*(\d+)', content)
      m_server = re.search(r'const\s+char\s*\*\s*mqtt_server\s*=\s*"([^"]*)"', content)
      m_port = re.search(r'const\s+int\s+mqtt_port\s*=\s*(\d+)', content)
      if not all([m_mask, m_server, m_port]):
          return None
      return {
          "net_prefix": f"{octet_map['a']}.{octet_map['b']}.{octet_map['c']}",
          "net_mask": int(m_mask.group(1)),
          "mqtt_server": m_server.group(1),
          "mqtt_port": int(m_port.group(1)),
      }
  ```

- [ ] **Step 5: Run all tests — confirm all pass**

  ```bash
  cd tool && pytest tests/test_utils.py -v
  ```

  Expected: All tests PASS (including the 5 new ones).

- [ ] **Step 6: Commit**

  ```bash
  git add tool/ltl_programmer.py tool/tests/test_utils.py
  git commit -m "feat: add read_network_from_credentials() with tests"
  ```

---

## Task 3: Update LTL_sensor.ino

**Files:**
- Modify: `code/LTL_sensor/LTL_sensor.ino`

- [ ] **Step 1: Open the file and locate the hardcoded values**

  Read `code/LTL_sensor/LTL_sensor.ino`. Identify these three blocks to change (exact text, not line numbers — the file may shift as edits are applied):
  - The `IPAddress staticIP/gateway/subnet/dns` block with `192, 168, 120`
  - The `const char* mqtt_server` and `const int mqtt_port` declarations

- [ ] **Step 2: Add static_assert and constexpr subnet after the #include "credentials.h" line**

  Find `#include "credentials.h"` and add immediately after it (before any other declarations):

  ```cpp
  static_assert(net_mask >= 1 && net_mask <= 30,
      "net_mask in credentials.h must be between 1 and 30 (e.g. 24 for /24)");

  // Convert CIDR prefix length to 4-octet subnet mask.
  // net_mask is guaranteed 1–30 by static_assert above, so the shift is always defined.
  // _subnet_bits must be declared here (global scope, before the IPAddress objects below).
  constexpr uint32_t _subnet_bits = 0xFFFFFFFFu << (32 - net_mask);
  ```

- [ ] **Step 3: Replace the hardcoded IPAddress block**

  Replace:
  ```cpp
  // Static IP (last octet = room number)
  IPAddress staticIP(192, 168, 120, roomNumber);
  IPAddress gateway(192, 168, 120, 1);
  IPAddress subnet(255, 255, 255, 0);
  IPAddress dns(192, 168, 120, 1);
  ```

  With:
  ```cpp
  // Static IP (last octet = room number) — prefix from credentials.h
  IPAddress staticIP(net_a, net_b, net_c, roomNumber);
  IPAddress gateway (net_a, net_b, net_c, 1);
  IPAddress subnet  ((_subnet_bits>>24)&0xFF, (_subnet_bits>>16)&0xFF,
                     (_subnet_bits>>8)&0xFF,   _subnet_bits&0xFF);
  IPAddress dns     (net_a, net_b, net_c, 1);
  ```

- [ ] **Step 4: Remove the hardcoded mqtt_server and mqtt_port declarations**

  Delete these two lines entirely (they are now provided by `credentials.h`):
  ```cpp
  const char* mqtt_server = "192.168.120.2";
  const int mqtt_port = 1883;
  ```

- [ ] **Step 5: Verify the file looks correct**

  Read the full updated file and confirm:
  - `static_assert` appears after `#include "credentials.h"`
  - `_subnet_bits` `constexpr` appears before the `IPAddress` declarations
  - All four `IPAddress` objects use `net_a/b/c` (no `192, 168, 120` literals remain)
  - `mqtt_server` and `mqtt_port` are not declared in the firmware (they come from credentials)

- [ ] **Step 6: Commit**

  ```bash
  git add code/LTL_sensor/LTL_sensor.ino
  git commit -m "feat: replace hardcoded network values with credentials.h constants"
  ```

---

## Task 4: Update TUI — show network info in credentials panel

**Files:**
- Modify: `tool/ltl_programmer.py`

### What to change

The `#creds-panel` currently contains a `DataTable` only. We need to:
1. Add a `Static` widget (`#creds-info`) below the table in `compose()`
2. Add CSS for `#creds-info`
3. Handle `DataTable.RowHighlighted` to update `#creds-info` when the cursor moves

- [ ] **Step 1: Add the CSS rule for #creds-info**

  In the `CSS` string of `LTLProgrammerApp` (around line 481), find the `#creds-title` rule block. Add after it:

  ```css
  #creds-info {
      color: #cdd6f4;
      padding: 0 1;
      height: auto;
  }
  ```

- [ ] **Step 2: Add the Static widget to compose()**

  In `compose()` (around line 598), find the `with Vertical(id="creds-panel"):` block:

  ```python
  with Vertical(id="creds-panel"):
      yield Label(" ✦  Credentials", id="creds-title")
      yield DataTable(id="creds-table", cursor_type="row")
  ```

  Add the info widget after the DataTable:

  ```python
  with Vertical(id="creds-panel"):
      yield Label(" ✦  Credentials", id="creds-title")
      yield DataTable(id="creds-table", cursor_type="row")
      yield Static("", id="creds-info")
  ```

- [ ] **Step 3: Add the _update_creds_info() helper method**

  Add this method to `LTLProgrammerApp`, after `_apply_refresh` (around line 636):

  ```python
  def _update_creds_info(self) -> None:
      """Refresh the network info block for the currently selected credentials row."""
      info = self.query_one("#creds-info", Static)
      if not self._credentials:
          info.update("")
          return
      table = self.query_one("#creds-table", DataTable)
      idx = table.cursor_row
      if idx < 0 or idx >= len(self._credentials):
          info.update("")
          return
      location = self._credentials[idx]
      cred_path = PROJECT_ROOT / f"credentials_{location}.h"
      net = read_network_from_credentials(cred_path)
      if net is None:
          info.update("[yellow]⚠ Netzwerkkonfiguration fehlt[/yellow]")
      else:
          info.update(
              f"[#585b70]Netz[/#585b70]   {net['net_prefix']}.0/{net['net_mask']}\n"
              f"[#585b70]MQTT[/#585b70]   {net['mqtt_server']}:{net['mqtt_port']}"
          )
  ```

- [ ] **Step 4: Call _update_creds_info() from _apply_refresh()**

  Note: `#creds-info` will appear blank for the first ~2s at startup (until the background port scan completes). Once the scan finishes, `_apply_refresh()` populates the credentials table, moves the cursor to row 0, and calls `_update_creds_info()` — after which the info block is always populated when credentials are present.

  In `_apply_refresh()` (around line 656), find the block that updates the credentials table:

  ```python
  if creds != self._credentials:
      table = self.query_one("#creds-table", DataTable)
      table.clear()
      for loc in creds:
          table.add_row(loc, f"credentials_{loc}.h")
      self._credentials = creds
  ```

  Add `table.move_cursor(row=0)` and `self._update_creds_info()` at the end of that block. The cursor move triggers the `RowHighlighted` event and ensures `#creds-info` is populated immediately after the credentials list loads — without it, the info widget stays blank until the user manually navigates.

  ```python
  if creds != self._credentials:
      table = self.query_one("#creds-table", DataTable)
      table.clear()
      for loc in creds:
          table.add_row(loc, f"credentials_{loc}.h")
      self._credentials = creds
      table.move_cursor(row=0)
      self._update_creds_info()
  ```

- [ ] **Step 5: Handle DataTable.RowHighlighted to update on cursor movement**

  Add this event handler to `LTLProgrammerApp`, after the `on_key` handler (around line 685):

  ```python
  def on_data_table_row_highlighted(self, event: DataTable.RowHighlighted) -> None:
      if event.data_table.id == "creds-table":
          self._update_creds_info()
  ```

- [ ] **Step 6: Run the TUI manually and verify**

  ```bash
  cd tool && python3 ltl_programmer.py
  ```

  Move the cursor in the credentials table. The `#creds-info` area should show:
  ```
  Netz   192.168.120.0/24
  MQTT   192.168.120.2:1883
  ```
  For a credentials file that lacks the new fields, it should show:
  ```
  ⚠ Netzwerkkonfiguration fehlt
  ```

- [ ] **Step 7: Commit**

  ```bash
  git add tool/ltl_programmer.py
  git commit -m "feat: show network config in credentials panel"
  ```

---

## Task 5: Update real credentials_*.h files

**Files:**
- Modify: Any `credentials_*.h` files present locally (gitignored, not in repo)

- [ ] **Step 1: Find all local credentials files**

  Run from the project root (`LongTermEnvLogger/`):

  ```bash
  ls credentials_*.h 2>/dev/null
  ```

- [ ] **Step 2: Add the five new fields to each file**

  For each `credentials_<location>.h`, add the five new constants with the correct values for that location. Use `credentials.example.h` as reference for the comment format. Example for a home network `192.168.120.x`:

  ```c
  const uint8_t  net_a       = 192;
  const uint8_t  net_b       = 168;
  const uint8_t  net_c       = 120;
  const uint8_t  net_mask    = 24;
  const char*    mqtt_server = "192.168.120.2";
  const int      mqtt_port   = 1883;
  ```

  Adjust values for each location (School, etc.) as appropriate.

  Note: These files are gitignored and must NOT be committed.

- [ ] **Step 3: Verify TUI shows correct info**

  Run `python3 ltl_programmer.py` and confirm the network info block shows the correct values for each credentials file.

---

## Task 6: Final check and run all tests

- [ ] **Step 1: Run the full test suite**

  ```bash
  cd tool && pytest -v
  ```

  Expected: All tests PASS.

- [ ] **Step 2: Confirm no hardcoded 192.168.120 octets remain in firmware**

  ```bash
  grep -n "192, 168, 120\|192\.168\.120\|mqtt_server\s*=\|mqtt_port\s*=" code/LTL_sensor/LTL_sensor.ino
  ```

  Expected: No output (all hardcoded values removed).

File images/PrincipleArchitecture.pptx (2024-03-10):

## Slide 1

MQTT

MQTT

Grafana

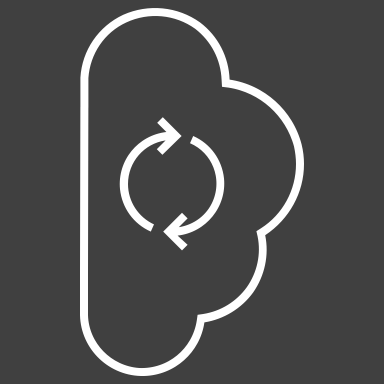
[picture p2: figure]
Synchronisierende Cloud Silhouette

MQTT

InfluxDB

MQTT

Telegraf

MQTT

MQTT Broker
(mosquitto)

MQTT

MQTT

MQTT

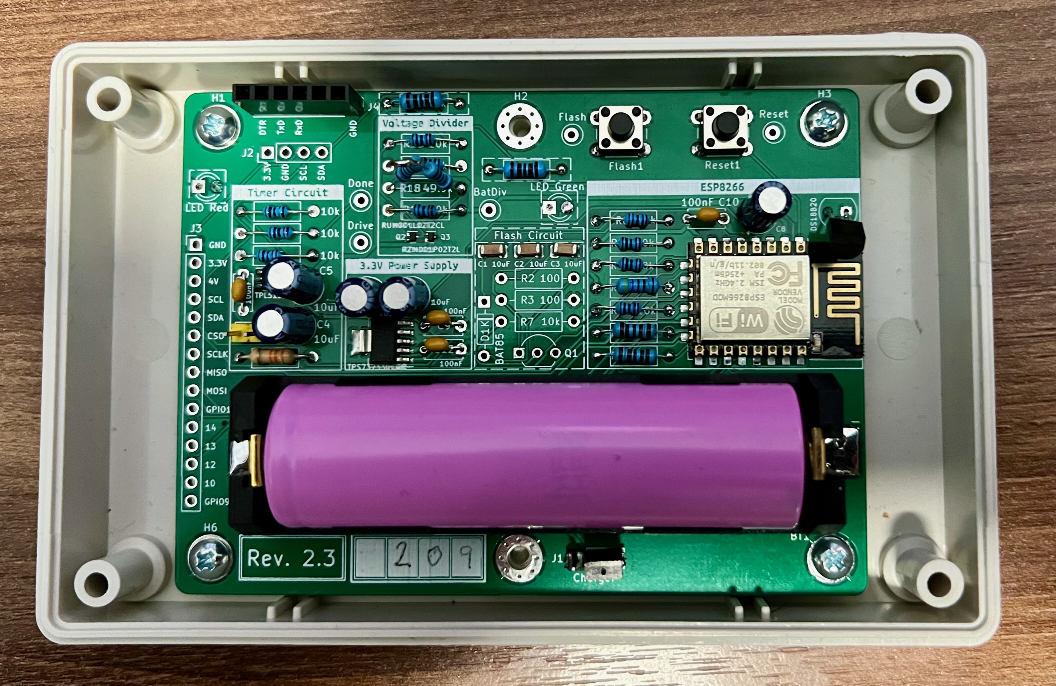
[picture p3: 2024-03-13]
images/LTL Revision 2.3.jpeg

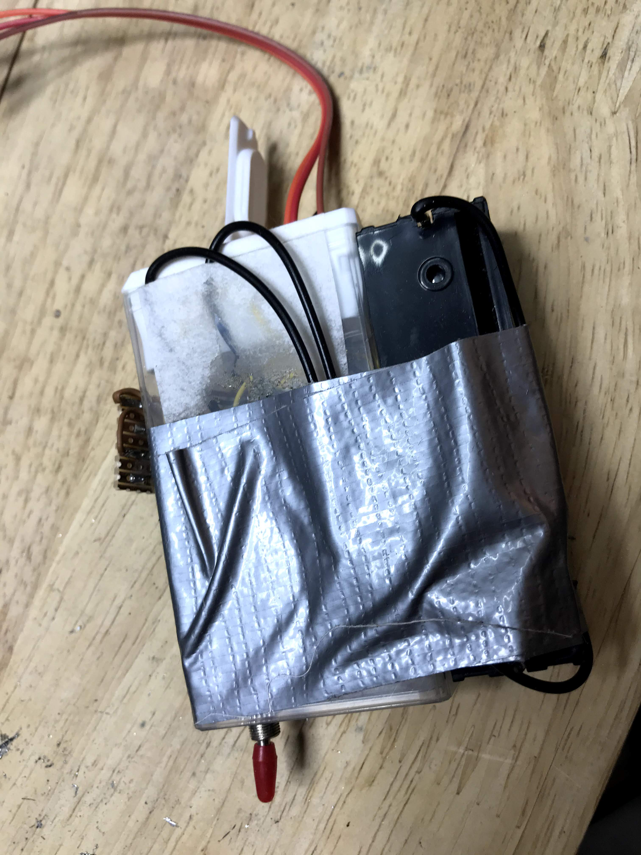
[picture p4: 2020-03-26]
images/LTL Revision 0.1.jpg

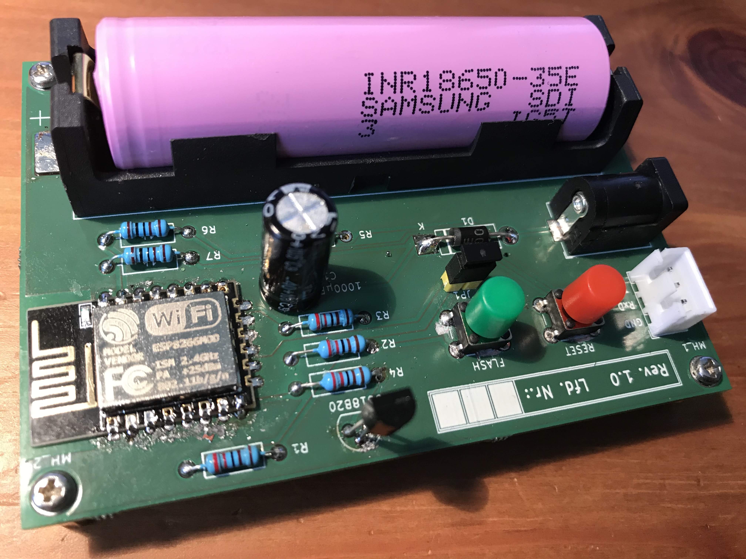
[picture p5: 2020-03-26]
images/LTL Revision 1.0.jpg

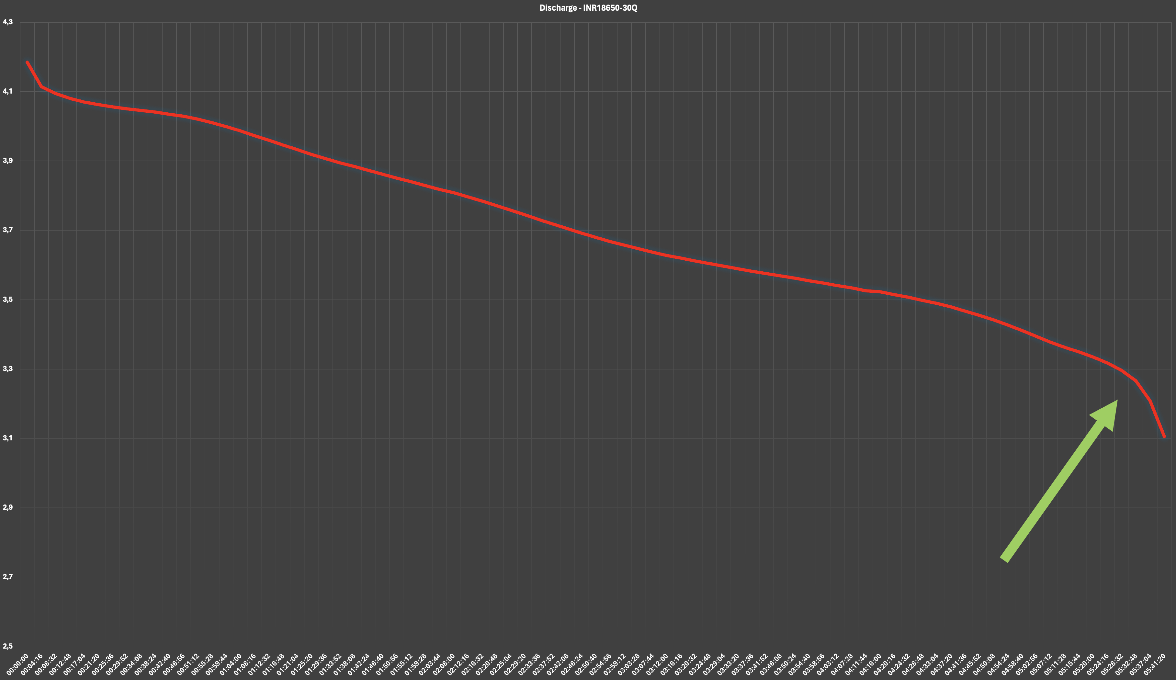
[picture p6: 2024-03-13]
images/Discharge_INR18650-30Q.png

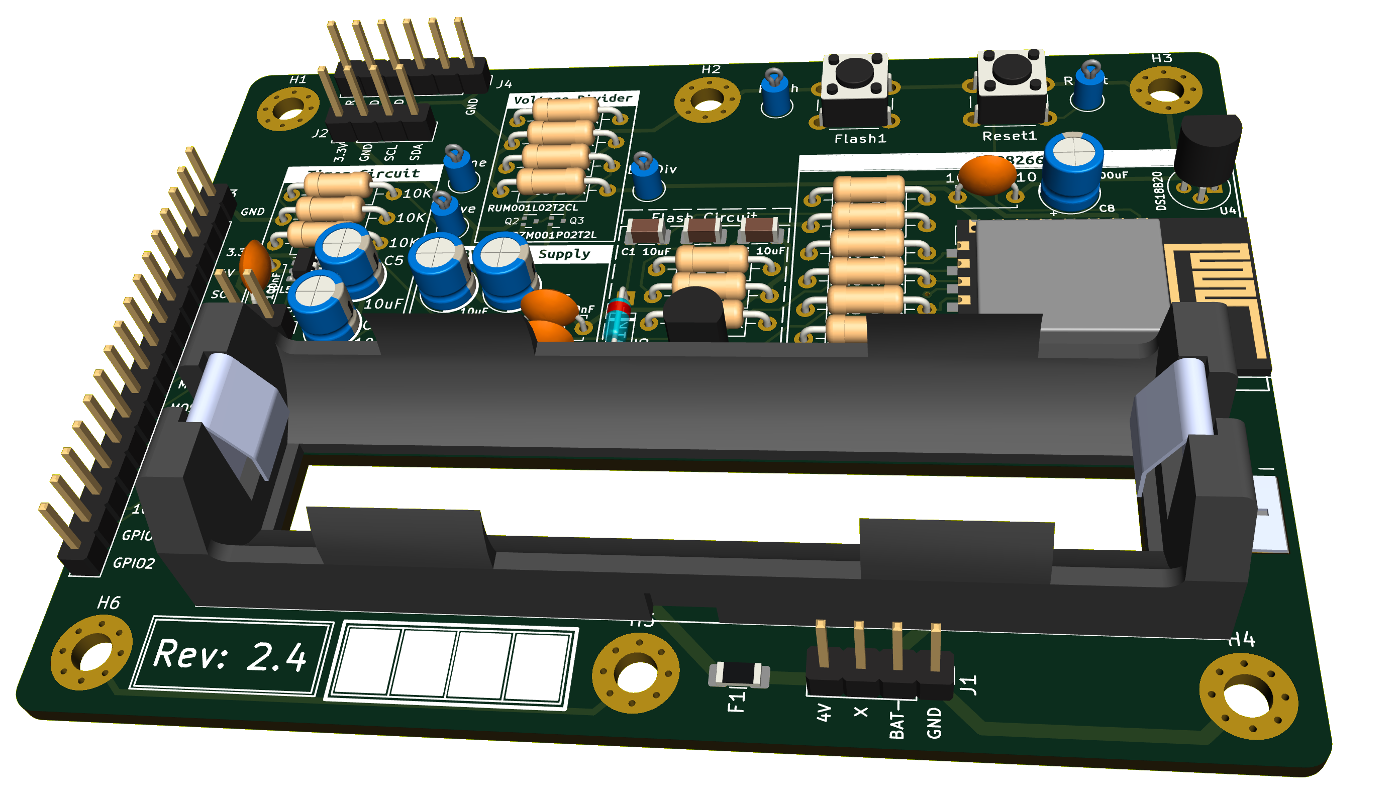
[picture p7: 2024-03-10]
images/LTL Revision 2.4.png

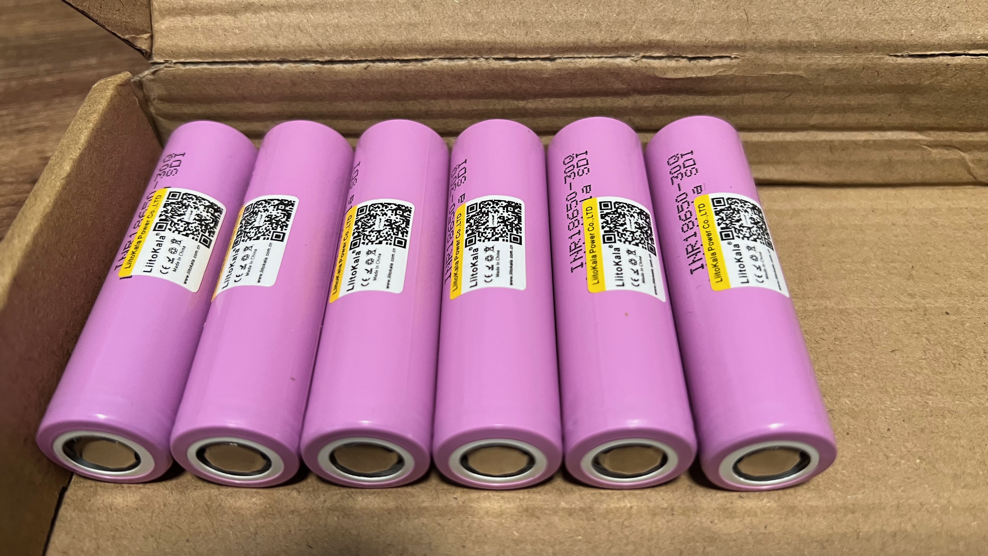
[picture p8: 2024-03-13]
images/INR18650-30Q.jpeg

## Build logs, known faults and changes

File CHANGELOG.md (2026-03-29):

# Changelog

## [Unreleased]

## [1.2.0] — 2026-03-29 — Credentials UX, Debug Panel & Code Quality

### Added

- **`tool/ltl_programmer.py`** — Per-location sensor registry
  - Separate `sensors_<location>.csv` per credentials file (e.g. `sensors_home.csv`, `sensors_school.csv`)
  - Auto-creates the CSV when switching credentials if none exists yet
  - Switching credentials in the panel immediately reloads the matching registry

- **`tool/ltl_programmer.py`** — Always-visible Serial Debug panel
  - Dedicated `RichLog` strip at the bottom showing every raw line received from the ESP during setup-sketch read
  - Non-focusable (excluded from Tab order and active-panel highlighting)

- **`tool/ltl_programmer.py`** — Baud rate selector and serial retry loop
  - `Select` widget in the flash overlay lets the user pick 9600 / 74880 / 115200 / 230400 / 460800 baud before flashing
  - On serial read timeout, the overlay re-appears with a "Retry →" button; user can change baud and retry without reflashing

- **`tool/ltl_programmer.py`** — Two-column credentials panel
  - Left column: scrollable file list with `>` indicator and bright-green highlight on selected file; blue "Location / File" sub-header
  - Right column: network info (IP, Network, Gateway, DNS, MQTT Broker) with blue "Contents" sub-header
  - `CredsList` custom widget renders with Rich `Text` (no-wrap, ellipsis overflow)

### Changed

- **`tool/ltl_programmer.py`** — Panel title styling
  - All panel titles always shown with inverted colours (blue background, dark text)
  - Active panel title highlighted in neon yellow (`#ffff00`) matching the active frame border
  - "Status" panel renamed to "System Log"

- **`tool/ltl_programmer.py`** — OTA port filtering
  - `detect_ports()` skips ports where `arduino-cli board list` reports `protocol == "network"`, eliminating OTA device noise from the Serial Ports panel

- **`tool/ltl_programmer.py`** — All UI strings now English
  - Modals (`NewCredentialsModal`, `ConfirmModal`, `RegistryEntryModal`) previously used German labels, buttons, and error messages — all translated
  - Inline comments in `write_credentials_file` translated

### Fixed

- **`tool/ltl_programmer.py`** — Thread safety: `baud_rate` is now read via `_get_baud_rate()` which schedules a `call_from_thread` read, eliminating the DOM race condition in the serial retry worker
- **`tool/ltl_programmer.py`** — `TemporaryDirectory` for production firmware now uses a `with` block — guaranteed cleanup even if compilation or upload raises
- **`tool/ltl_programmer.py`** — `credentials.h` copy in setup sketch directory is now always removed via `try/finally`, even on early-exit compile/upload failures
- **`tool/ltl_programmer.py`** — `write_network_to_credentials` and `write_credentials_file` raise `ValueError` on malformed IP segment counts instead of `IndexError`
- **`tool/ltl_programmer.py`** — `NewCredentialsModal` rejects SSID/password containing `"` to prevent C-string injection in generated `.h` files
- **`tool/ltl_programmer.py`** — Compile error log now shows `stdout` when `stderr` is empty (`arduino-cli` writes error detail to `stdout` in some failure modes)
- **`tool/ltl_programmer.py`** — `detect_ports` now catches all exceptions (not just `FileNotFoundError` and `TimeoutExpired`)
- **`tool/ltl_programmer.py`** — `load_csv_rooms` uses `_room_int` helper — no `ValueError` crash on manually-edited CSVs with non-integer room numbers
- **`tool/ltl_programmer.py`** — `parse_serial_output` guards `int()` conversion on WIFI `channel`/`rssi` fields — malformed ESP lines are silently skipped

### Refactored

- **`tool/ltl_programmer.py`** — `_compile` promoted to module-level `_compile_sketch()` — independently unit-testable, no class dependency
- **`tool/ltl_programmer.py`** — `FlashOverlay` exposes `trigger_continue()` public method; `LTLProgrammerApp.on_key` no longer accesses private `_continue_event` directly
- **`tool/ltl_programmer.py`** — `_PANEL_IDS` no longer includes the debug panel; active-panel CSS for debug removed
- **`tool/ltl_programmer.py`** — Dead attribute `self._button_label` removed from `FlashOverlay.show_instructions`

## [1.1.0] — 2026-03-23 — TUI Panel Highlight & Network Config

### Changed

- **`tool/ltl_programmer.py`** — Visual improvements to panel selection
  - All four panels unified to the same blue (`#89b4fa`) border and title colour
  - Active panel highlighted with a heavy neon-yellow (`#ffff00`) border and filled blue title
  - Initial active panel correctly set to Serial Ports (matching Textual's default focus)
  - Fixed: programmatic `move_cursor()` calls no longer steal the active highlight from the focused panel
  - `_set_active_panel` short-circuits when the panel hasn't changed (eliminates 5 redundant DOM queries per focus event)
  - Panel ID mapping extracted to a class-level constant `_PANEL_IDS`
  - App header styled with a double blue frame and increased height

- **`tool/ltl_programmer.py`** — Network config write-back
  - `write_network_to_credentials()` — writes gateway, DNS, MQTT, and subnet back to `credentials_*.h`
  - Network edit dialog (`NetworkConfigScreen`) for editing config in-TUI

- **`credentials.example.h`** — Gateway and DNS now explicit fields instead of derived from `net_prefix.1`

- **`code/LTL_sensor/LTL_sensor.ino`** — Uses explicit `gw_*` / `dns_*` constants from credentials

## [1.0.0] — 2026-03-23 — Battery Optimization & Programmer Tool

### Added

- **`tool/ltl_programmer.py`** — Interactive TUI programmer tool (Textual, Catppuccin Mocha dark theme)
  - Two-step ESP8266 flash workflow (setup sketch → production firmware)
  - Auto-detection of USB serial ports with live hotplug refresh every 2 s
  - Pre-selection of `usbserial` port and matching credentials SSID
  - Auto-selection of strongest WiFi signal matching the credentials SSID (BSSID pinning)
  - Parallel background compilation while user prepares hardware
  - Continue button disabled until compiler finishes (visual feedback)
  - Combined flash-mode + run-mode instruction screen (single screen per step)
  - Sensor registry panel (newest entry first, timestamp display)
  - CSV upsert — each room appears only once, newest flash overwrites
  - Room number overwrite warning with Enter-to-confirm support
  - Full keyboard navigation: F Flash, R Refresh, Q Quit, Enter Confirm
  - Clean shutdown on Q without hanging background threads

- **`code/LTL_setup/LTL_setup.ino`** — Setup/discovery sketch for ESP8266
  - Reads DS18B20 OneWire address, MAC address, and nearby WiFi networks
  - Outputs structured lines (`MAC:`, `DS18B20:`, `WIFI:`, `SETUP_DONE`) at 115200 baud

- **`code/LTL_sensor/LTL_sensor.ino`** — Optimized production firmware
  - 9-bit DS18B20 resolution (±0.5°C) with async conversion overlapped with WiFi connect
  - Hardcoded DS18B20 address (no bus scan on each wake)
  - Optional BSSID + channel pinning for faster WiFi reconnection (~200–400 ms saved)
  - Low-battery cutoff (ADC threshold, prevents LiIon deep discharge)
  - Publishes temperature and voltage via MQTT
  - Hardware power-off via GPIO15 DONE signal

- **`tool/arduino_config.py`** — Board FQBN and timing constants
- **`tool/requirements.txt`** — Python dependencies (`textual`, `pyserial`, `rich`, `pytest`)
- **`tool/tests/test_utils.py`** — Unit tests for all pure utility functions
- **`credentials.example.h`** — Template for WiFi credentials (never commit real credentials)

### Changed

- README updated: TUI tool documentation, keyboard shortcuts, updated prerequisites (Python 3.10+, `pip install -r tool/requirements.txt`)

---

## [0.2.0] — 2024-03-08 — Hardware Prototyping

- KiCad schematic and PCB layout for sensor hardware
- LiIon battery circuit with protection and solar charging

## [0.1.0] — 2024-03-06 — Initial Firmware

- First working ESP8266 sketch with DS18B20 and MQTT
- WiFi credentials moved to separate `credentials.h` (gitignored)

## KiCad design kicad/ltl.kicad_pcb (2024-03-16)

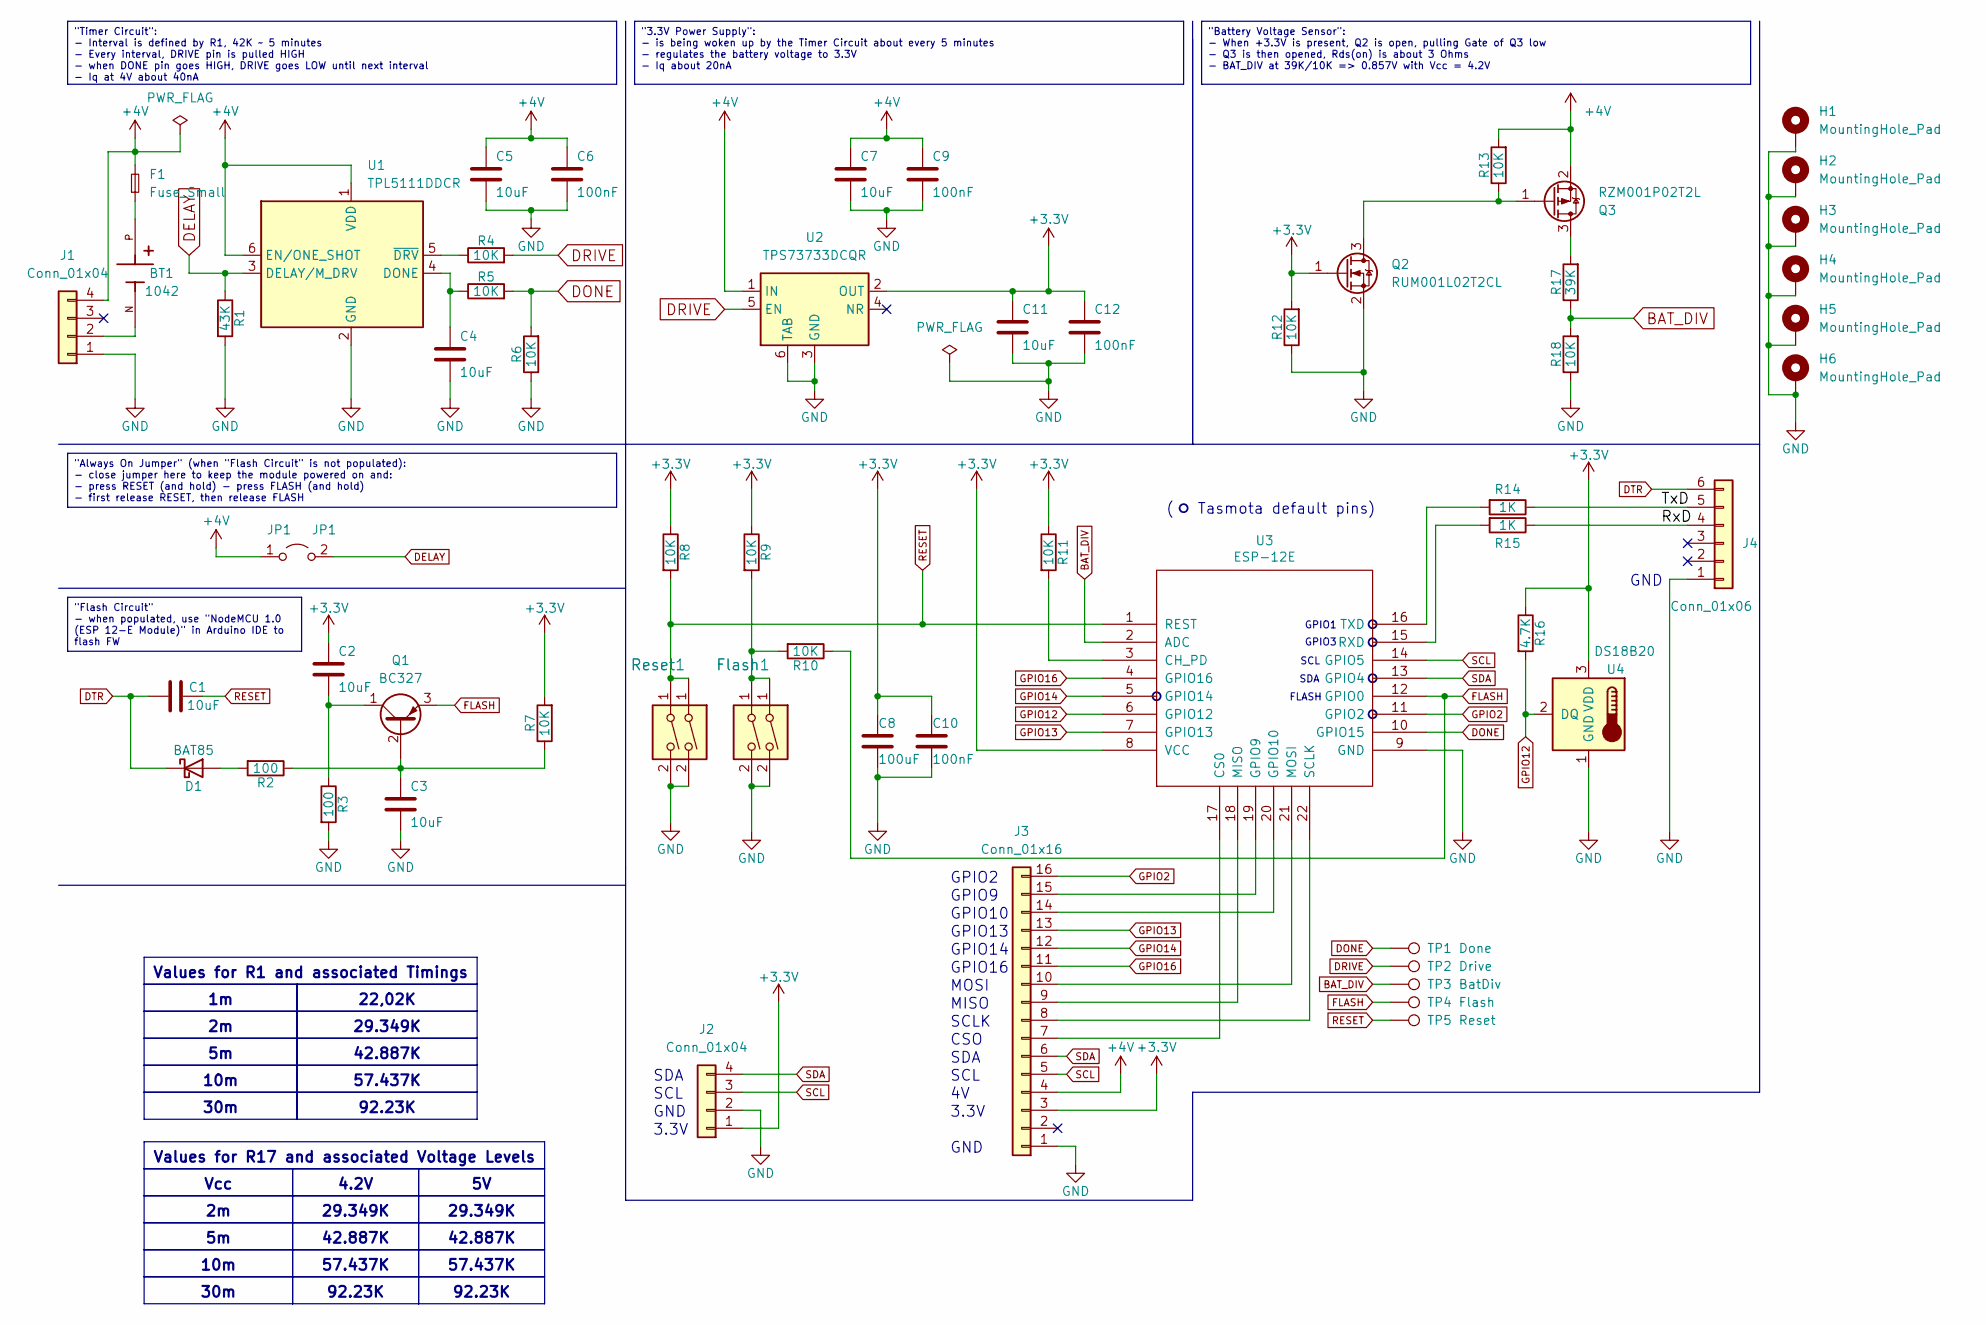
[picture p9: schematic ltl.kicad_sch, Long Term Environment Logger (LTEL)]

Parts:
BT1: 1042; 18650_flat; PARTREV E
C1, C2, C3: 10uF; C_1206_3216Metric
C4, C5, C7, C11: 10uF; CP_Radial_D5.0mm_P2.00mm
C6, C9, C10, C12: 100nF; C_Disc_D5.0mm_W2.5mm_P5.00mm
C8: 100uF; CP_Radial_D5.0mm_P2.00mm
D1: BAT85; D_DO-35_SOD27_P7.62mm_Horizontal
F1: Fuse_Small; Fuse_1206_3216Metric_Pad1.42x1.75mm_HandSolder
Flash1: Flash; SW_PUSH_6mm
H1, H2, H3, H4, H5, H6: MountingHole_Pad; MountingHole_3.2mm_M3_Pad_Via
J1, J2: Conn_01x04; PinHeader_1x04_P2.54mm_Vertical
J3: Conn_01x16; PinHeader_1x16_P2.54mm_Vertical
J4: Conn_01x06; PinHeader_1x06_P2.54mm_Vertical
JP1: JP1; PinHeader_1x02_P2.54mm_Vertical
Q1: BC327; TO-92_Inline_Wide
Q2: RUM001L02T2CL; SOT-723
Q3: RZM001P02T2L; SOT-723
R1: 43K; R_Axial_DIN0207_L6.3mm_D2.5mm_P10.16mm_Horizontal
R2, R3: 100; R_Axial_DIN0207_L6.3mm_D2.5mm_P10.16mm_Horizontal
R4, R5, R6, R7, R8, R9, R10, R11, R12, R13, R18: 10K; R_Axial_DIN0207_L6.3mm_D2.5mm_P10.16mm_Horizontal
R14, R15: 1K; R_Axial_DIN0207_L6.3mm_D2.5mm_P10.16mm_Horizontal
R16: 4.7K; R_Axial_DIN0207_L6.3mm_D2.5mm_P10.16mm_Horizontal
R17: 39K; R_Axial_DIN0207_L6.3mm_D2.5mm_P10.16mm_Horizontal
Reset1: Reset; SW_PUSH_6mm
TP1: Done; TestPoint_Loop_D1.80mm_Drill1.0mm_Beaded
TP2: Drive; TestPoint_Loop_D1.80mm_Drill1.0mm_Beaded
TP3: BatDiv; TestPoint_Loop_D1.80mm_Drill1.0mm_Beaded
TP4: Flash; TestPoint_Loop_D1.80mm_Drill1.0mm_Beaded
TP5: Reset; TestPoint_Loop_D1.80mm_Drill1.0mm_Beaded
U1: TPL5111DDCR; SOT-23-6
U2: TPS73733DCQR; SOT-223-6
U3: ESP-12E; ESP8266MOD
U4: DS18B20; TO-92

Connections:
+3V3: C2.1, C8.1, C10.1, C11.1, C12.1, J2.1, J3.3, Q2.1 (G), R7.2, R8.1, R9.1, R11.1, R12.2, R16.1, U2.2 (OUT), U3.8 (VCC), U4.3 (VDD)
+4V: C5.1, C6.1, C7.1, C9.1, F1.2, J1.4, J3.4, JP1.1 (A), Q3.2 (S), R13.2, U1.1 (VDD), U1.6 (EN/ONE_SHOT), U2.1 (IN)
/RxD: J4.4, R15.1
/TxD: J4.5, R14.1
BAT_DIV: R17.1, R18.2, TP3.1, U3.2 (ADC)
DELAY: JP1.2 (B), R1.1, U1.3 (DELAY/M_DRV)
DONE: R5.2, R6.2, TP1.1, U3.10 (GPIO15)
DRIVE: R4.2, TP2.1, U2.5 (EN)
DTR: C1.1, D1.1 (K), J4.6
FLASH: Q1.3 (E), R10.1, TP4.1, U3.12 (GPIO0)
GND: C3.2, C4.2, C5.2, C6.2, C7.2, C8.2, C9.2, C10.2, C11.2, C12.2, Flash1.2, H1.1, H2.1, H3.1, H4.1, H5.1, H6.1, J1.1, J2.2, J3.1, J4.1, Q2.2 (S), R1.2, R3.2, R6.1, R12.1, R18.1, Reset1.2, U1.2 (GND), U2.3 (GND), U2.6 (TAB), U3.9 (GND), U4.1 (GND)
GPIO2: J3.16, U3.11 (GPIO2)
GPIO12: R16.2, U3.6 (GPIO12), U4.2 (DQ)
GPIO13: J3.13, U3.7 (GPIO13)
GPIO14: J3.12, U3.5 (GPIO14)
GPIO16: J3.11, U3.4 (GPIO16)
unnamed: BT1.P, F1.1
unnamed: D1.2 (A), R2.2
unnamed: Flash1.1, R9.2, R10.2
unnamed: BT1.N, J1.2
unnamed: J3.7, U3.17 (CS0)
unnamed: J3.8, U3.22 (SCLK)
unnamed: J3.9, U3.18 (MISO)
unnamed: J3.10, U3.21 (MOSI)
unnamed: J3.14, U3.20 (GPIO10)
unnamed: J3.15, U3.19 (GPIO9)
unnamed: C3.1, Q1.2 (B), R2.1, R7.1
unnamed: C2.2, Q1.1 (C), R3.1
unnamed: Q2.3 (D), Q3.1 (G), R13.1
unnamed: Q3.3 (D), R17.2
unnamed: C4.1, R5.1, U1.4 (DONE)
unnamed: R4.1, U1.5 (~DRV)
unnamed: R11.2, U3.3 (CH_PD)
unnamed: R15.2, U3.15 (RXD)
unnamed: R14.2, U3.16 (TXD)
RESET: C1.2, R8.2, Reset1.1, TP5.1, U3.1 (REST)
SCL: J2.3, J3.5, U3.14 (GPIO5)
SDA: J2.4, J3.6, U3.13 (GPIO4)

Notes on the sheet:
42.887K
57.437K
92.23K
"Battery Voltage Sensor": - When +3.3V is present, Q2 is open, pulling Gate of Q3 low - Q3 is then opened, Rds(on) is about 3 Ohms - BAT_DIV at 39K/10K => 0.857V with Vcc = 4.2V
29.349K
Values for R17 and associated Voltage Levels
Vcc
"Timer Circuit": - Interval is defined by R1, 42K ~ 5 minutes - Every interval, DRIVE pin is pulled HIGH - when DONE pin goes HIGH, DRIVE goes LOW until next interval - Iq at 4V about 40nA
10m
"3.3V Power Supply": - is being woken up by the Timer Circuit about every 5 minutes - regulates the battery voltage to 3.3V - Iq about 20nA
4.2V
22,02K
"Always On Jumper" (when "Flash Circuit" is not populated): - close jumper here to keep the module powered on and: - press RESET (and hold) - press FLASH (and hold) - first release RESET, then release FLASH
30m
"Flash Circuit" - when populated, use "NodeMCU 1.0 (ESP 12-E Module)" in Arduino IDE to flash FW
Values for R1 and associated Timings
GPIO1
GPIO14
GPIO16
( Tasmota default pins)
GND
GPIO2
SDA
FLASH
GPIO9
MISO
SCL
CSO
MOSI
3.3V
GPIO10
SCLK
GPIO3
GPIO13

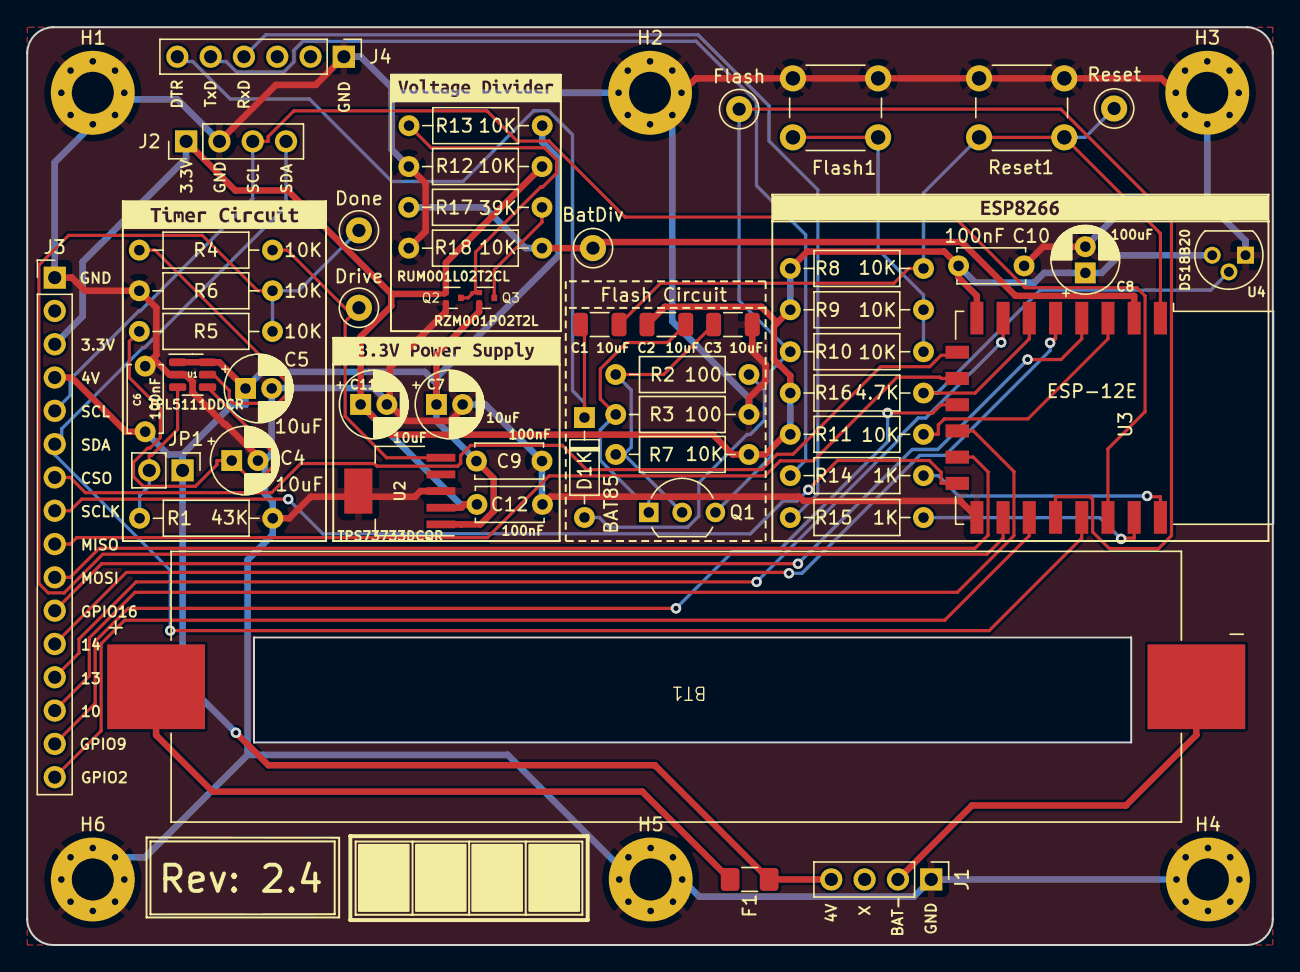
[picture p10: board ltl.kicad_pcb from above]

Board: 2 copper layers, 95.0 x 70.0 mm, 62 parts (0 on the bottom side), 38 nets.

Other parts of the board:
kibuzzard-65AD8C40: G***; kibuzzard-65AD8C40
kibuzzard-65AD86B5: G***; kibuzzard-65AD86B5
kibuzzard-65AD8212: G***; kibuzzard-65AD8212
kibuzzard-65AD8853: G***; kibuzzard-65AD8853

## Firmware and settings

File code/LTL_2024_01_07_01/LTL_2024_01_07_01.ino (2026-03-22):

#include <ESP8266WiFi.h>
#include <PubSubClient.h>
#include <OneWire.h>
#include <DallasTemperature.h>
#include "credentials.h"

// define a 3-digit room number
const int roomNumber = 101;


// define voltage limit to prevent deep discharge
const int volt_limit = 560;

// Static IP configuration
IPAddress staticIP(192, 168, 120, roomNumber); // Assigned static IP address
IPAddress gateway(192, 168, 120, 1);    // Gateway (usually your router IP)
IPAddress subnet(255, 255, 255, 0);     // Subnet mask
IPAddress dns(192, 168, 120, 1);        // DNS (can be the same as the Gateway)

// Example BSSID of the WiFi network and channel
// BSSID for N-IOT 82:8a:20:d1:77:51
// const uint8_t wifi_bssid[6] = {0x82, 0x8a, 0x20, 0xd1, 0x77, 0x51};
// BSSID for HCG_IoT
const uint8_t wifi_bssid[6] = {0xEE, 0x55, 0xA8, 0x2C, 0xA8, 0x64};
// const int wifi_channel = 6;

// MQTT Server
const char* mqtt_server = "192.168.120.2";
const int mqtt_port = 1883;

// Format MQTT topics to include the device number
char temp_topic[30];
char volt_topic[30];

// Data wire is plugged into GPIO12
#define ONE_WIRE_BUS 12
// GPIO15, to be set HIGH when finished
#define DONE 15
// Setup temperature sensor
OneWire oneWire(ONE_WIRE_BUS);
DallasTemperature sensors(&oneWire);

WiFiClient espClient;
PubSubClient client(espClient);

void setup_wifi() {
  // we track time to make sure that we stop connecting after 5 seconds, in case WiFi is down
  unsigned long startAttemptTime = millis();

  // Waking up WiFi modem and connect to WiFi
  WiFi.forceSleepWake();
  char hostname[11];
  sprintf(hostname, "sensor_%03d", roomNumber);
  WiFi.hostname(hostname);
  WiFi.config(staticIP, gateway, subnet, dns);
  // WiFi.begin(ssid, password, wifi_channel, wifi_bssid);
  WiFi.begin(ssid, password);
  // Try for 5 seconds to connect to WiFi (should take about 2 seconds)
  while (WiFi.status() != WL_CONNECTED && millis() - startAttemptTime < 5000) {
    delay(100);
  }

  // if no connection, directly switch off circuit until next try
  if(WiFi.status() != WL_CONNECTED) {
    digitalWrite(DONE, HIGH);
  }
}

void reconnect() {
  char clientId[20];
  // Define room number as Client ID
  sprintf(clientId, "room_%03d", roomNumber);
  // Format the MQTT topics
  sprintf(temp_topic, "sensor/temp/%03d", roomNumber);
  sprintf(volt_topic, "sensor/volt/%03d", roomNumber);

  client.setServer(mqtt_server, mqtt_port);
  
  // Start timer
  signed long startAttemptTime = millis();

  while (!client.connected()) {
    if (client.connect(clientId)) {
      // Connected to the MQTT broker
      break; // Exit the loop
    } else {
      delay(100); // Wait for a short period before retrying
      
      if (millis() - startAttemptTime > 5000) {
        // If more than 5 seconds have passed without a connection,
        // set DONE high to indicate the device should go to sleep
        digitalWrite(DONE, HIGH);
      }
    }
  }
}

void setup() {
  // Ensure WiFi is turned off to save energy
  WiFi.forceSleepBegin();
  // Start sensors
  sensors.begin();
  // Set DONE pin to be output
  pinMode(DONE, OUTPUT);
}

void loop() {
  
  // Measure voltage first
  
  // if voltage is below 2.7V, go asleep to make sure
  // the battery is not below its discharge limit
  int adcValue = analogRead(A0);
  if (adcValue < volt_limit) {
    // If voltage is lower than 560, go to sleep
    digitalWrite(DONE, HIGH);
    return; // Stop execution here
  }
  char payload[5];
  snprintf(payload, sizeof(payload), "%d", adcValue);

  // Measure temperature
  sensors.requestTemperatures();
  float temperature = sensors.getTempCByIndex(0);
  char tempString[8];
  dtostrf(temperature, 1, 2, tempString);
  
  
  // Then turn on WiFi
  setup_wifi();
  // Ensure MQTT connection
  if (!client.connected()) { reconnect(); }
  client.loop();
  // Publish temperature and voltage
  // if (!client.publish(temp_topic, tempString)) { }
  client.publish(temp_topic, tempString);
  delay(100);
  // if (!client.publish(volt_topic, payload)) { }
  client.publish(volt_topic, payload);
  delay(200);
  // Switch off circuit
  digitalWrite(DONE, HIGH);
}

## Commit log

2018-02-01 Second commit
    [Noko PCB.kicad_pcb, Noko PCB.sch]
2018-02-01 added PDF directory
    [ltl.sch]
2018-02-01 Changes in scope, not limited to temperature only
2018-04-02 some minor changes
    [ltl.sch]
2020-03-12 Kleinere Änderungen
    [Laufzeitberechnung.ods]
2020-03-15 letzte Änderungen
    [Laufzeitberechnung.ods, ltl-2020-03-12-22-45-38.sch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]
2020-03-19 Zweite Revision der Leiterplatte, mehrere Fehler beseitigt: - Schalter Symbol und Footprint haben nicht übereingestimmt (Nummerierung), dadurch nur mit Schwierigkeiten einsetzbar (3 Leiterbahnen müss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
    Desweiteren noch ein aktualisiertes 3D Image der Leiterplatte hinzugefügt.
    Anonsten ist der erste Prototyp funktionsfähig :)
    [ltl-B_Cu.gbr, ltl-B_Mask.gbr, ltl-B_Paste.gbr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]
2020-03-19 Schaltplan aktualisiert
    [ltl.sch]
2020-03-26 Viele Änderungen, siehe Wiki
    [Preis und Laufzeitberechnung.ods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]
2020-03-26 Anpassungen im README.md und Schaltplanaktualisierung
    [ltl.sch]
2020-06-25 ch ch ch changes
    [Preis und Laufzeitberechnung.ods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]
2023-12-12 Added timer and voltage regulator for low power requirements
    [ltl.kicad_pcb, ltl.kicad_sch]
2023-12-27 Lots of added features and bug fixes
    [freerouting.dsn, ltl.kicad_pcb, ltl.kicad_sch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]
2024-01-09 Latest PCB version, sent for production
    [ltl-B_Cu.gbr, ltl-B_Mask.gbr, ltl-B_Paste.gbr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]
2024-02-02 Updated PCB to Revision 2.2
    [freerouting.dsn, ltl-2020-03-12-22-45-38.sch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]
2024-02-02 Added PCB 3D image
2024-03-06 Created .gitignore and move credentials to credentials.h
    [LTL Statistik.xlsx]
2024-03-10 A couple of addictions
    [LTL Statistik.xlsx, ltl.dsn, ltl.kicad_pcb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]
2024-03-10 Removed unused files
    [LTL Statistik.xlsx, Laufzeitberechnung.ods]
2024-03-13 Updated last image
    [ltl.dsn, ltl.kicad_pcb, ltl.kicad_sch]
2024-03-13 Added UART adapter image
2024-03-13 Added Charger Picture
2024-03-16 Updated code to account for WiFi and MQTT broker outages and several other cleanups
    [ltl-B_Cu.gbr, ltl-B_Mask.gbr, ltl-B_Silkscreen.gbr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]
2026-03-22 Add design spec for battery optimization and programmer tool
2026-03-22 Add implementation plan for battery optimization and programmer tool
2026-03-22 feat: add tool foundation — arduino_config.py and ltl_programmer.py skeleton
2026-03-22 feat: add arduino-cli flash and serial data reader
2026-03-22 feat: rewrite programmer tool as Textual TUI with full workflow
    - Full Textual TUI (Catppuccin Mocha dark theme)
    - FlashOverlay with instruction + progress modes in one widget
    - Auto-detect USB port (preselect usbserial), hotplug refresh
    - Auto-select BSSID from credentials SSID (strongest signal)
    - Background parallel compilation while user preps hardware
    - Continue button disabled until compiler finishes
    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
2026-03-22 chore: resolve .gitignore merge conflict
    [LTL_2024_01_07_01.ino]
2026-03-22 docs: update README and add CHANGELOG
    - README: reflect TUI tool, keyboard shortcuts, updated prerequisites,
    removed manual WiFi selection step (now auto), Python 3.10+ requirement
    - CHANGELOG: document battery optimization release and historical changes
2026-03-23 feat: add WiFi connection test to setup sketch
    - LTL_setup.ino now includes credentials.h and attempts a real WiFi
    connection after scanning — reports WIFI_OK or WIFI_FAIL on serial
    - ltl_programmer.py copies credentials_<location>.h to the setup sketch
    dir before compilation and removes it afterwards
    - parse_serial_output handles WIFI_OK / WIFI_FAIL
    - Workflow aborts with clear error if WiFi connection fails
    [LTL_setup.ino, ltl_programmer.py]
2026-03-23 feat: remove BSSID pinning
    WiFi connects by SSID only — no BSSID or channel baked into firmware.
2026-03-23 feat: add read_network_from_credentials() with tests
    Also fixes pre-existing gap: format_bssid_c_array and append_csv_row
    were imported by test_utils.py but absent from ltl_programmer.py.
    [ltl_programmer.py]
2026-03-23 fix: add length validation to format_bssid_c_array with test
    [ltl_programmer.py]
2026-03-23 feat: replace hardcoded network values with credentials.h constants
    [LTL_sensor.ino]
2026-03-23 feat: TUI panel highlighting, network config write-back, and cleanup
    Panel UX:
    - All four panels share a unified blue (#89b4fa) border and title colour
    - Active panel shown with a heavy neon-yellow (#ffff00) border and filled title
    - Initial focus correctly lands on Serial Ports at startup
    - Programmatic move_cursor() no longer steals the active highlight
    - _set_active_panel short-circuits on no-op (removes 5 redundant DOM queries)
    - _PANEL_IDS extracted as class-level constant
    Network config:
    - write_network_to_credentials() writes gateway/DNS/MQTT/subnet back to credentials_*.h
    - NetworkConfigScreen dialog for in-TUI editing
    - credentials.example.h: gateway and DNS are now explicit fields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
    [LTL_sensor.ino, ltl_programmer.py]
2026-03-23 feat: per-credentials sensor registry (sensors_<location>.csv)
    Instead of a single sensors.csv, the registry is now scoped to the
    selected credentials file — e.g. credentials_Home.h uses sensors_Home.csv.
    The registry reloads automatically when switching credentials rows.
2026-03-23 feat: auto-create sensors_<location>.csv when switching credentials
    Switching credentials rows now always loads the matching registry file.
    If the file does not yet exist it is created with just the header row,
    so the Sensor Registry panel is ready immediately without manual setup.
2026-03-27 fix: ignore network (OTA) ports in detect_ports()
    arduino-cli board list reports WiFi/OTA devices with protocol "network".
    These entries caused the Status panel to flood with connect/disconnect
    messages as the OTA ESP cycled. Skip any line where protocol == "network".
    [ltl_programmer.py]
2026-03-27 feat: baud rate selector in flash overlay
    Adds a Select widget to the flash instruction panel showing common
    ESP8266 baud rates (9600, 74880, 115200, 230400, 460800), defaulting
    to the configured BAUD_RATE (115200). The chosen rate is captured on
    the main thread when Flash is pressed and passed through to serial.Serial,
    making it easy to diagnose garbled output caused by baud mismatch
    (e.g. ROM bootloader at 74880).
2026-03-27 feat: retry serial read with adjustable baud rate on timeout
    On SETUP_DONE timeout, re-shows the flash overlay with the baud rate
    selector and a Retry button instead of aborting. The user can switch
    baud rate (e.g. to 74880 for ROM bootloader output), power-cycle the
    ESP, and retry without re-flashing. Q still aborts cleanly.
2026-03-27 fix: correct method name _show_flash_instructions in serial retry loop
    _wait_step does not exist — the correct method is _show_flash_instructions.
    [ltl_programmer.py]
2026-03-27 fix: hide flash overlay after serial retry is confirmed
    After the user clicked Retry, _show_flash_instructions returned but
    _clear_step() was never called, leaving the overlay on screen while the
    next serial read ran silently in the background for 30 s. Added
    _clear_step() immediately after reading the new baud rate so the overlay
    dismisses and the Status log becomes visible again.
    [ltl_programmer.py]
2026-03-28 feat: make Serial Debug panel always visible
    Removed the T toggle — the debug panel is now permanently shown below
    the main layout. Dropped the toggle binding and action_toggle_debug.
    [ltl_programmer.py]
2026-03-28 feat: rename network labels and translate UI to English
    Credentials info panel: Netz→Network, MQTT→MQTT Broker, added 'E to edit' hint.
    NetworkConfigModal: full English labels, title, validation messages, buttons.
    action_ctx_edit: English notification strings.
    [ltl_programmer.py]
2026-03-28 feat: replace credentials DataTable with styled ListView
    All credential files are always visible. The selected entry is
    highlighted with a neon-yellow left border and bold yellow text.
    Unselected entries are shown in muted colour. Uses ListView/ListItem
    instead of DataTable; all references to creds-table cursor_row updated
    to ListView.index.
    [ltl_programmer.py]
2026-03-28 refactor: replace ListView with custom CredsList widget in credentials panel
    - Split credentials panel into 2 columns (file list left, network info right)
    - Custom CredsList widget renders with Rich Text for bright green > indicator
    on selected file and muted grey for others
    - Replaced on_list_view_highlighted with on_creds_list_changed handler
    - Removed ListView/ListItem imports (no longer used)
    [ltl_programmer.py]
2026-03-28 fix: stabilize credentials file list column layout
    - Wrap CredsList in a fixed-width (44 col) Vertical with "Location / File" header
    - Replace width:auto (which collapsed and caused text wrapping) with width:1fr inside fixed column
    - Add no_wrap=True to Rich Text renderer so long names never reflow
    - Border highlight moves to #creds-list-col so it tracks focus correctly
    [ltl_programmer.py]
2026-03-28 fix: credentials panel visual polish
    - Parameter labels (IP, Network, etc.) now white instead of muted grey
    - "Location / File" subheader centered with full-width separator line below
    [ltl_programmer.py]
2026-03-28 feat: inverted panel titles, yellow active highlight, debug non-focusable
    - All panel titles now show blue-inverted (bg #89b4fa, text dark) by default
    - Active panel title switches to yellow (bg #ffff00) matching the frame border
    - Serial Debug removed from _PANEL_IDS and debug-log.can_focus = False so it
    is skipped in Tab order and never highlighted as the active panel
    [ltl_programmer.py]
2026-03-28 rename: Status panel → System Log
2026-03-29 fix: apply all code quality review findings
    Critical:
    - _get_baud_rate() helper reads baud via call_from_thread — eliminates DOM
    access race condition from worker thread in serial retry loop
    - TemporaryDirectory now uses with-block; guaranteed cleanup on exceptions
    - setup_cred (credentials.h copy) wrapped in try/finally so it is always
    removed even when compilation or upload fails early
    Important:
    - write_network_to_credentials / write_credentials_file now raise ValueError
    on malformed IP segment counts instead of IndexError
    - NewCredentialsModal rejects SSID/password containing double-quote chars
    to prevent C-string injection in generated .h files
    - Compile error logs now show s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
    [ltl_programmer.py]
2026-03-29 chore: release v1.2.0
    - VERSION file introduced (1.2.0)
    - __version__ = "1.2.0" added to ltl_programmer.py
    - CHANGELOG updated with full v1.2.0 entry covering all changes since v1.1.0;
    prior entries retroactively tagged as v0.1.0, v0.2.0, v1.0.0, v1.1.0
    - README updated: new features (debug panel, baud retry, 2-column credentials,
    per-location CSV, E shortcut), sensor registry section updated
    [ltl_programmer.py]
2026-03-29 docs: add Excalidraw system architecture diagram
    Shows the full data pipeline: ESP8266+DS18B20 sensor nodes → WiFi →
    MQTT Broker (Mosquitto) → Telegraf → InfluxDB → Grafana,
    with the upward data-flow arrow and colour-coded component layers.
